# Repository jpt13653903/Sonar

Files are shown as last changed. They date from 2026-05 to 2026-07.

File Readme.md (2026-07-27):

# Sonar

Project used as a teaching aid for the [UCT FPGA course](https://github.com/jpt13653903/UCT-FPGA-Course).

## Overview

This DE10-Lite daughter card features transmitter and receiver array for a 10 kHz sonar system.

Block Diagram

## Flexible Grid

The design features a 64-element grid of microphone sites and a connection matrix that supports 16 output channels.  The user can populate up to 16 microphones and then use the matrix to route them to the receiver channels.

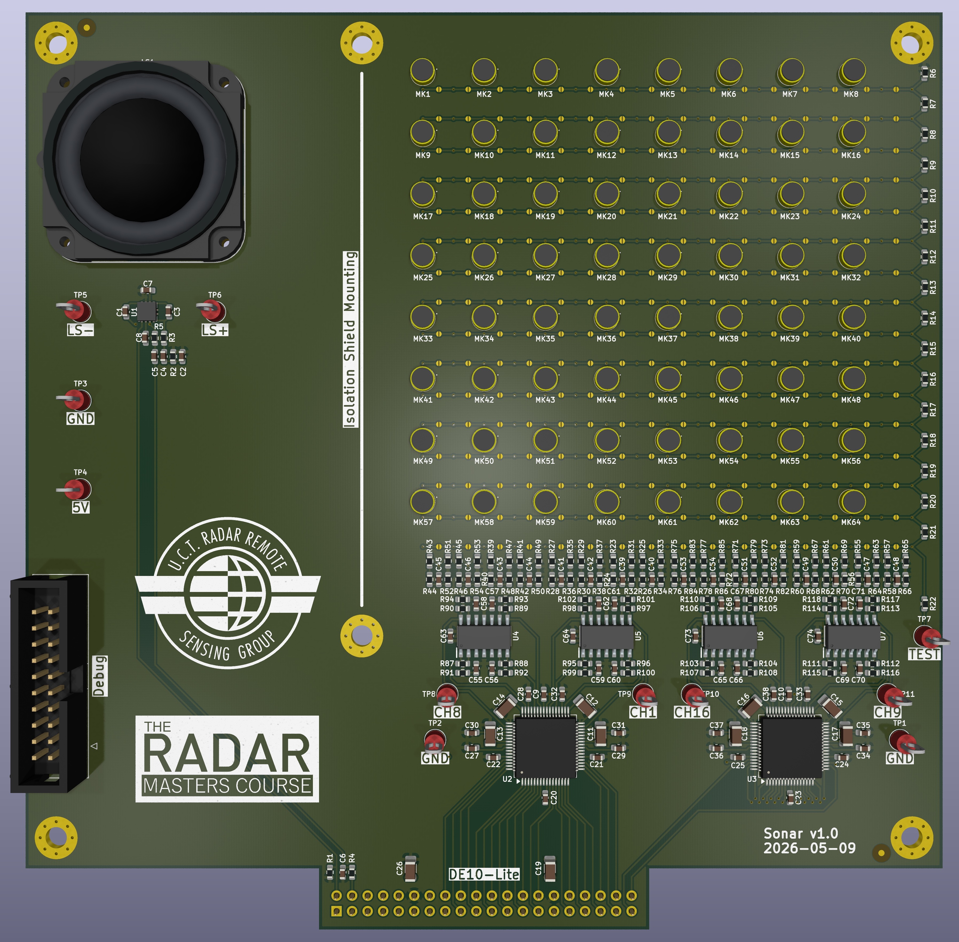
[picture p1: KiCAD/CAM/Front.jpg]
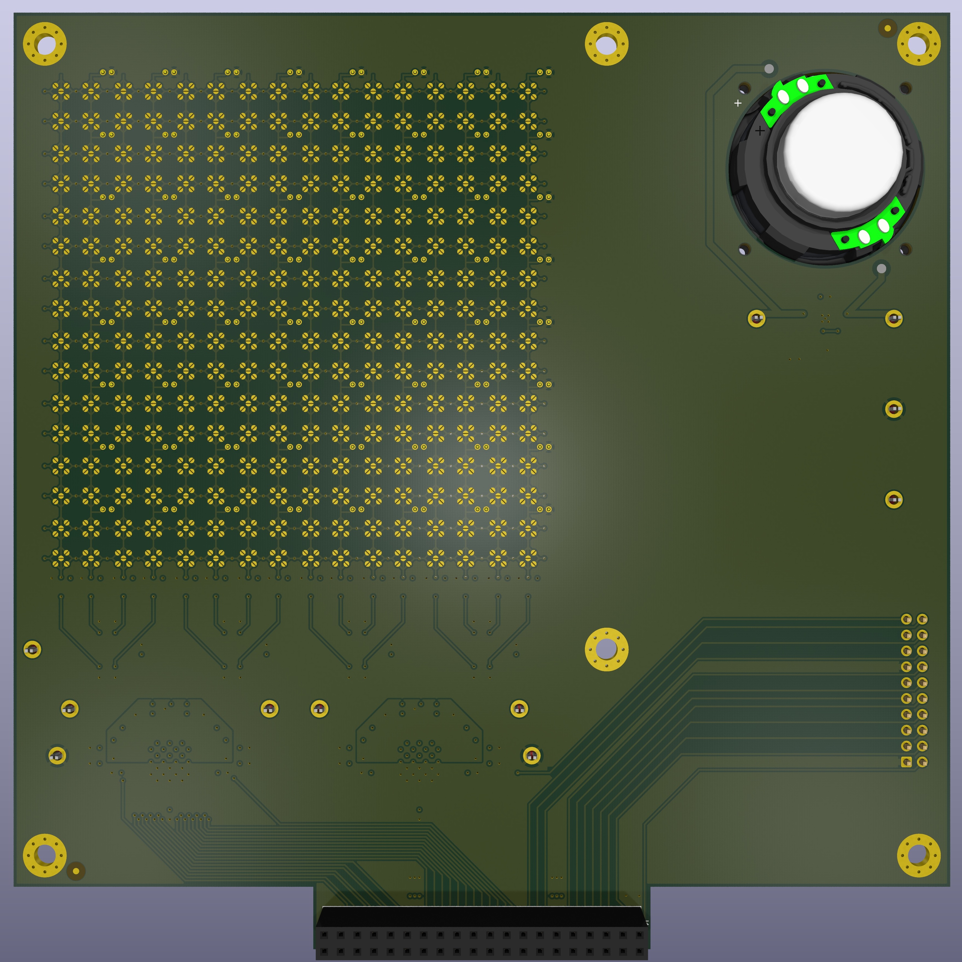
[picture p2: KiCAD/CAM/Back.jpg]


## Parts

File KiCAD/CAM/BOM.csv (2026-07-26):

Reference | Qty | Value | MPN | Manufacturer
C1,C3 | 2 | C0603_100p | KGM15AR71H101K | KYOCERA AVX
C2,C6 | 2 | C0603_2n2 | GRM1885C1H222JA01D | Murata
C4,C5,C8 | 3 | C0603_220n | GCM188R71E224MA55J | Murata
C7,C39,C40,C41,C42,C43,C44,C45,C46,C47,C48,C49,C50,C51,C52,C53,C54 | 17 | C0603_1u0 | GRT188R61H105KE13D | MuRata
C9,C10,C20,C21,C22,C23,C24,C25,C27,C28,C29,C30,C31,C32,C33,C34,C35,C36,C37,C38,C55,C56,C57,C58,C59,C60,C61,C62,C63,C64,C65,C66,C67,C68,C69,C70,C71,C72,C73,C74 | 40 | C0603_100n | 06035C104KAT2A | KYOCERA AVX
C11,C12,C13,C14,C15,C16,C17,C18,C19,C26 | 10 | C1206_22u | C1206C226M4PACTU | Kemet
J1 | 1 | DIN-40-Female | M20-7832042 | Harwin
J2 | 1 | DIN-20 | 70246-2004 | Molex
R1,R2,R4,R91,R92,R93,R94,R99,R100,R101,R102,R107,R108,R109,R110,R115,R116,R117,R118 | 19 | R0603_1k0 | CRGP0603F1K0 | TE Connectivity
R3,R5 | 2 | R0603_12k | CRGP0603F12K | TE Connectivity
R6,R7,R8,R9,R10,R11,R12,R13,R14,R15,R16,R17,R18,R19,R20,R21 | 16 | R0603_10R | CRGP0603F10R | TE Connectivity
R22,R31,R33,R35,R37,R47,R49,R51,R53,R63,R65,R67,R69,R79,R81,R83,R85 | 17 | R0603_3k6 | CRGP0603F3K6 | TE Connectivity
R23,R25,R27,R29,R39,R41,R43,R45,R55,R57,R59,R61,R71,R73,R75,R77 | 16 | R0603_5k6 | CRGP0603F5K6 | TE Connectivity
R24,R26,R28,R30,R32,R34,R36,R38,R40,R42,R44,R46,R48,R50,R52,R54,R56,R58,R60,R62,R64,R66,R68,R70,R72,R74,R76,R78,R80,R82,R84,R86,R87,R88,R89,R90,R95,R96,R97,R98,R103,R104,R105,R106,R111,R112,R113,R114 | 48 | R0603_100k | CRGP0603F100K | TE Connectivity
TP1,TP2,TP3 | 3 | Keystone_5011_Black | 5011 | Keystone
TP4 | 1 | Keystone_5010_Red | 5010 | Keystone
TP5,TP6,TP7,TP8,TP9,TP10,TP11 | 7 | Keystone_5014_Yellow | 5014 | Keystone
U1 | 1 | TPA6211A1DRBR | TPA6211A1DRBR | Texas Instruments
U2,U3 | 2 | MAX11059 | MAX11059ECB+ | Analog Devices
U4,U5,U6,U7 | 4 | AD8534ARZ-REEL | AD8534ARZ-REEL | Analog Devices

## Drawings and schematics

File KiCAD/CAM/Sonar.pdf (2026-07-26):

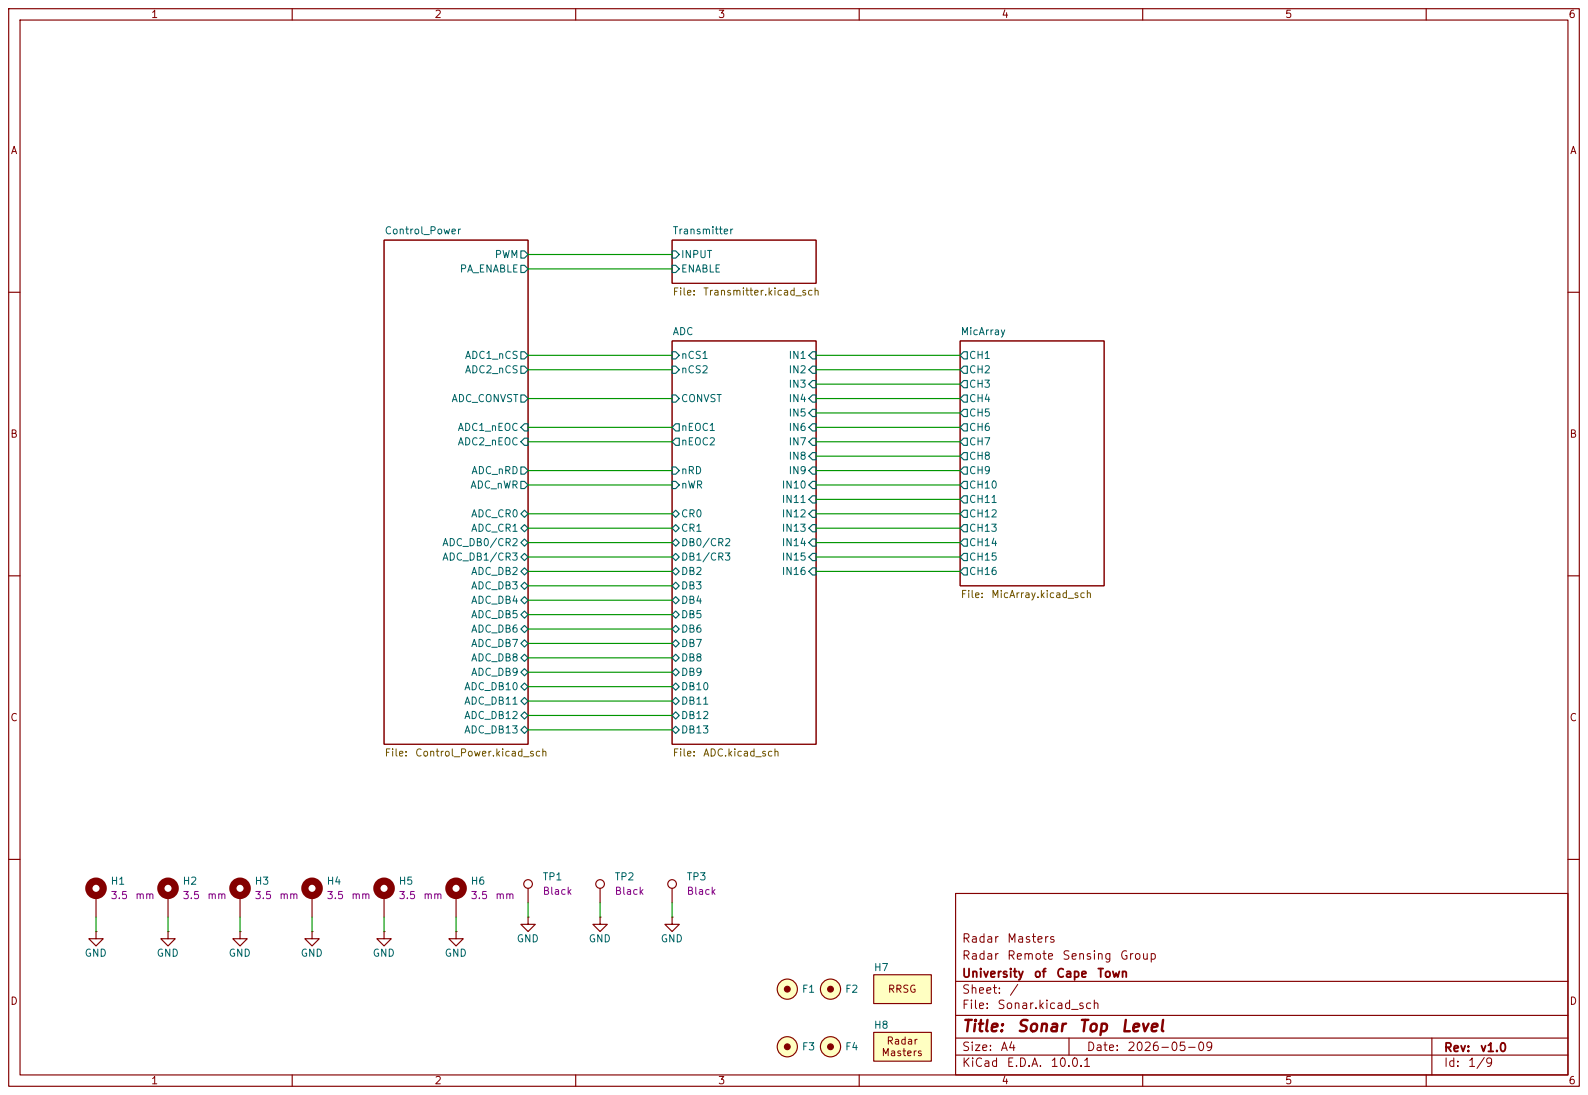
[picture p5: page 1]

Radar Remote Sensing Group
University of Cape Town
Sheet: /
File: Sonar.kicad_sch
Title: Sonar Top Level

Size: A4 | Rev: v1.0
KiCad E.D.A. 10.0.1 | Id: 1/9

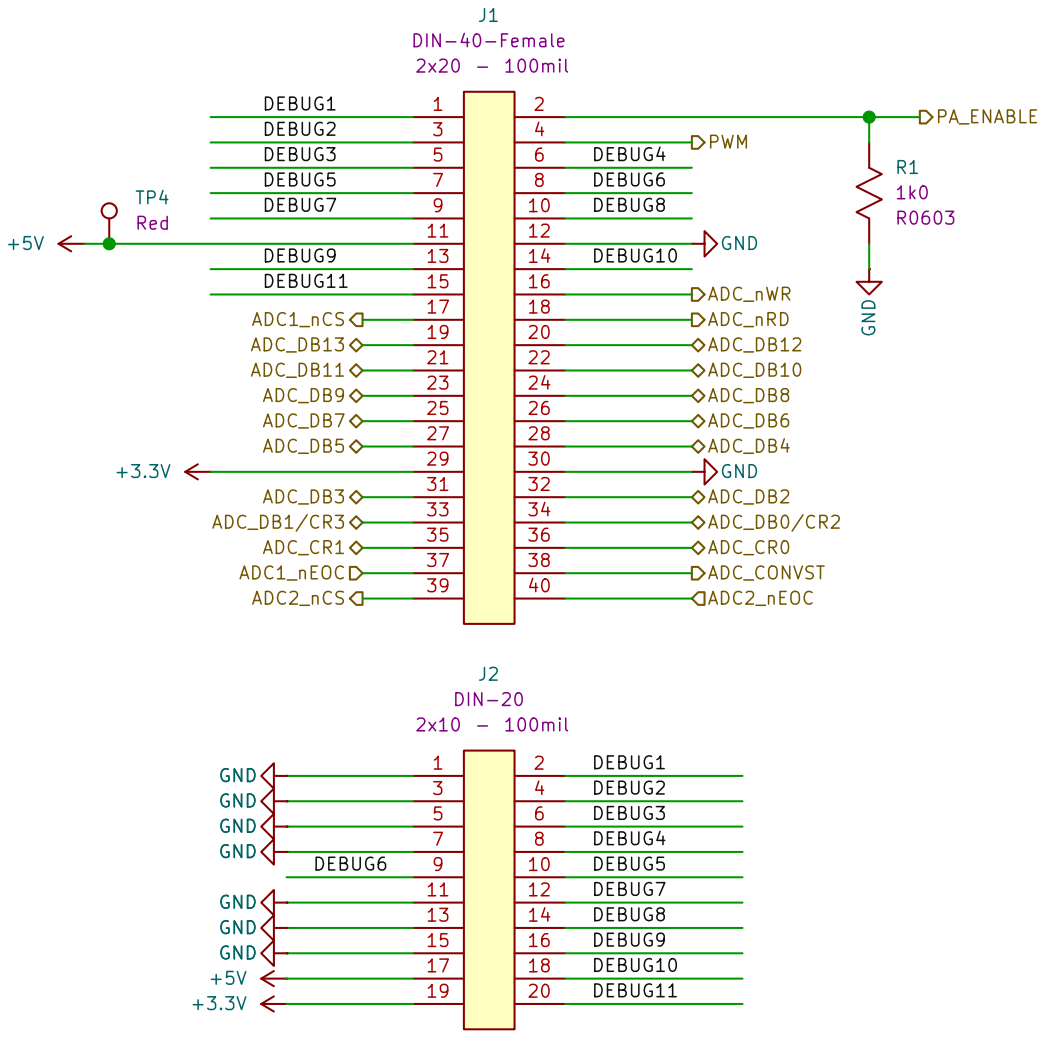
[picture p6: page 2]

Radar Remote Sensing Group
University of Cape Town
Sheet: /Control_Power/
File: Control_Power.kicad_sch
Title: Control and Power

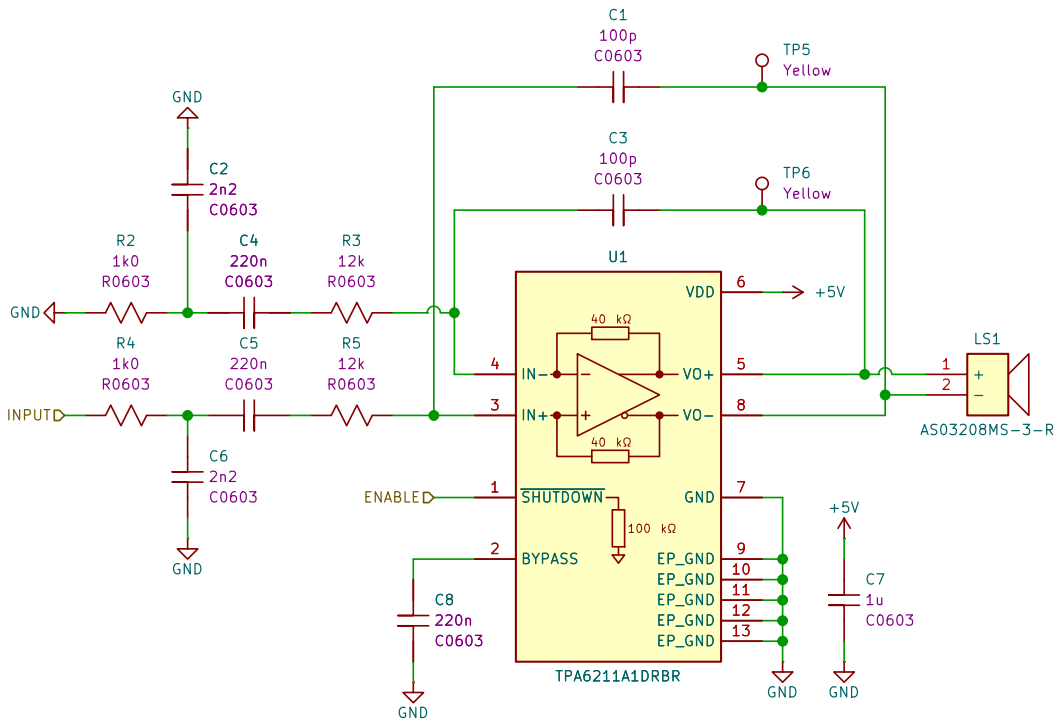
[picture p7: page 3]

Radar Masters
Radar Remote Sensing Group
University of Cape Town
Sheet: /Transmitter/
File: Transmitter.kicad_sch
Title: Transmitter

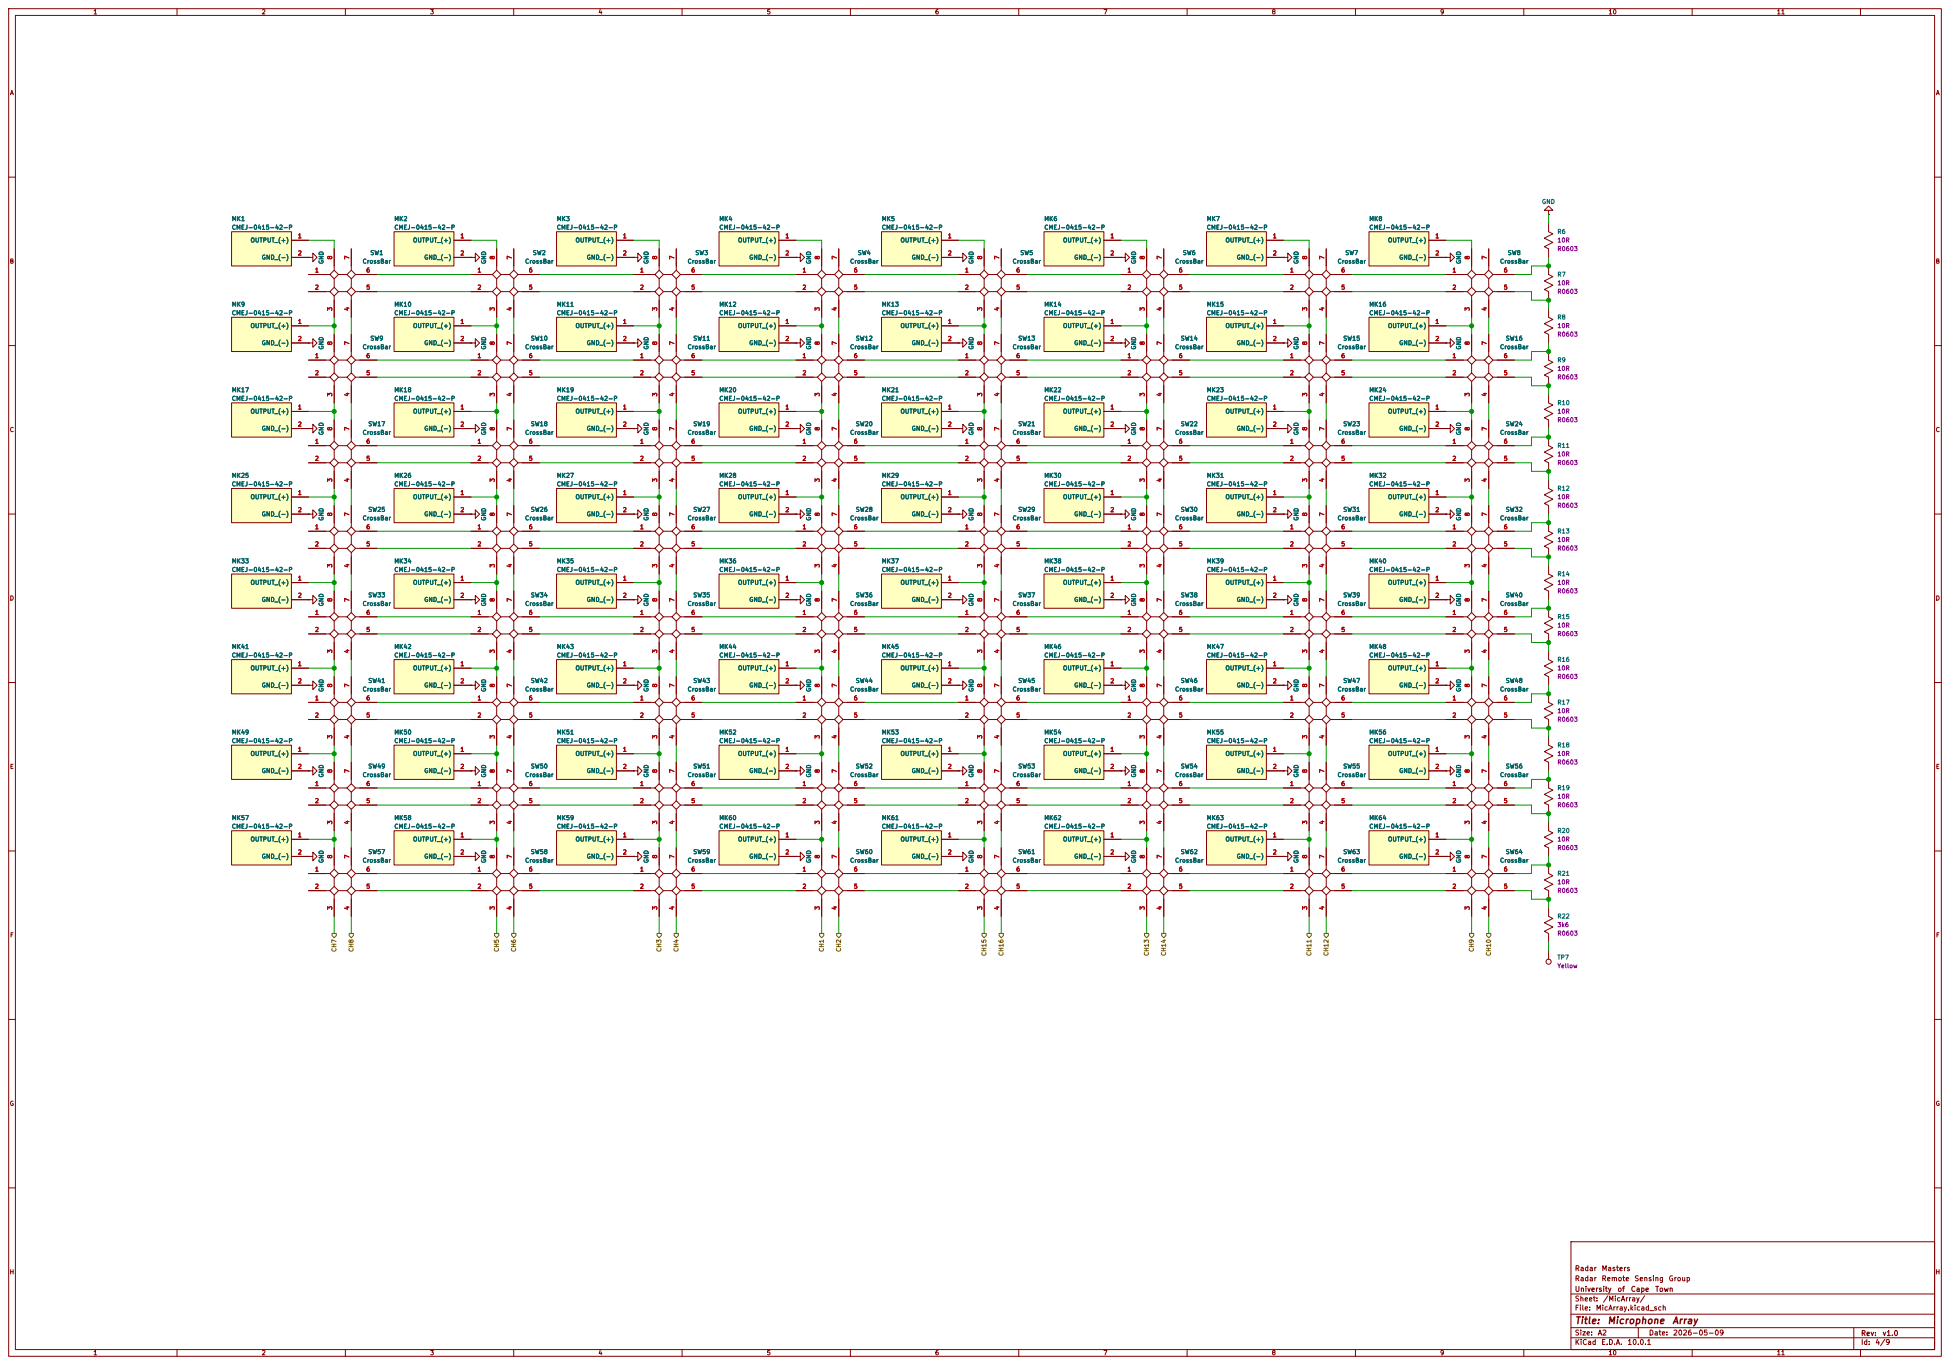
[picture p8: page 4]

7 MK17 CMEJ-0415-42-P OUTPUT_(+) 1 GND_(-) 2 GND MK9 CMEJ-0415-42-P OUTPUT_(+) 1 GND_(-) 2 GND MK1 CMEJ-0415-42-P OUTPUT_(+) 1 GND_(-) 2 GND

7 MK21 CMEJ-0415-42-P OUTPUT_(+) 1 GND_(-) 2 GND GND MK29 CMEJ-0415-42-P OUTPUT_(+) 1 GND_(-) 2 MK13 CMEJ-0415-42-P OUTPUT_(+) 1 GND_(-) 2 MK5 CMEJ-0415-42-P OUTPUT_(+) 1 GND_(-) 2 GND

7GND GND MK24 CMEJ-0415-42-P OUTPUT_(+) 1 GND_(-) 2 MK32 CMEJ-0415-42-P OUTPUT_(+) 1 GND_(-) 2 GND

SW23 CrossBar GND GND GND

7 GND GND MK19 CMEJ-0415-42-P OUTPUT_(+) 1 GND_(-) 2 MK50 CMEJ-0415-42-P OUTPUT_(+) 1 GND_(-) 2

7 MK33 CMEJ-0415-42-P OUTPUT_(+) 1 GND_(-) 2 MK25 CMEJ-0415-42-P OUTPUT_(+) 1 GND_(-) 2 GND GND GND MK59 CMEJ-0415-42-P OUTPUT_(+) 1 GND_(-) 2

7GND MK35 CMEJ-0415-42-P OUTPUT_(+) 1 GND_(-) 2 GND MK43 CMEJ-0415-42-P OUTPUT_(+) 1 GND_(-) 2 GND GND MK27 CMEJ-0415-42-P OUTPUT_(+) 1 GND_(-) 2 MK26 CMEJ-0415-42-P OUTPUT_(+) 1 GND_(-) 2 MK34 CMEJ-0415-42-P OUTPUT_(+) 1 GND_(-) 2

7 MK42 CMEJ-0415-42-P OUTPUT_(+) 1 GND_(-) 2 GND MK41 CMEJ-0415-42-P OUTPUT_(+) 1 GND_(-) 2 GNDSW33 CrossBar 1

7GND MK45 CMEJ-0415-42-P OUTPUT_(+) 1 GND_(-) 2 MK37 CMEJ-0415-42-P OUTPUT_(+) 1 GND_(-) 2 MK38 CMEJ-0415-42-P OUTPUT_(+) 1 GND_(-) 2 MK46 CMEJ-0415-42-P OUTPUT_(+) 1 GND_(-) 2

7GND MK49 CMEJ-0415-42-P OUTPUT_(+) 1 GND_(-) 2 MK57 CMEJ-0415-42-P OUTPUT_(+) 1 GND_(-) 2 GND GND

Radar Masters
Radar Remote Sensing Group
University of Cape Town
Sheet: /MicArray/
File: MicArray.kicad_sch
Title: Microphone Array

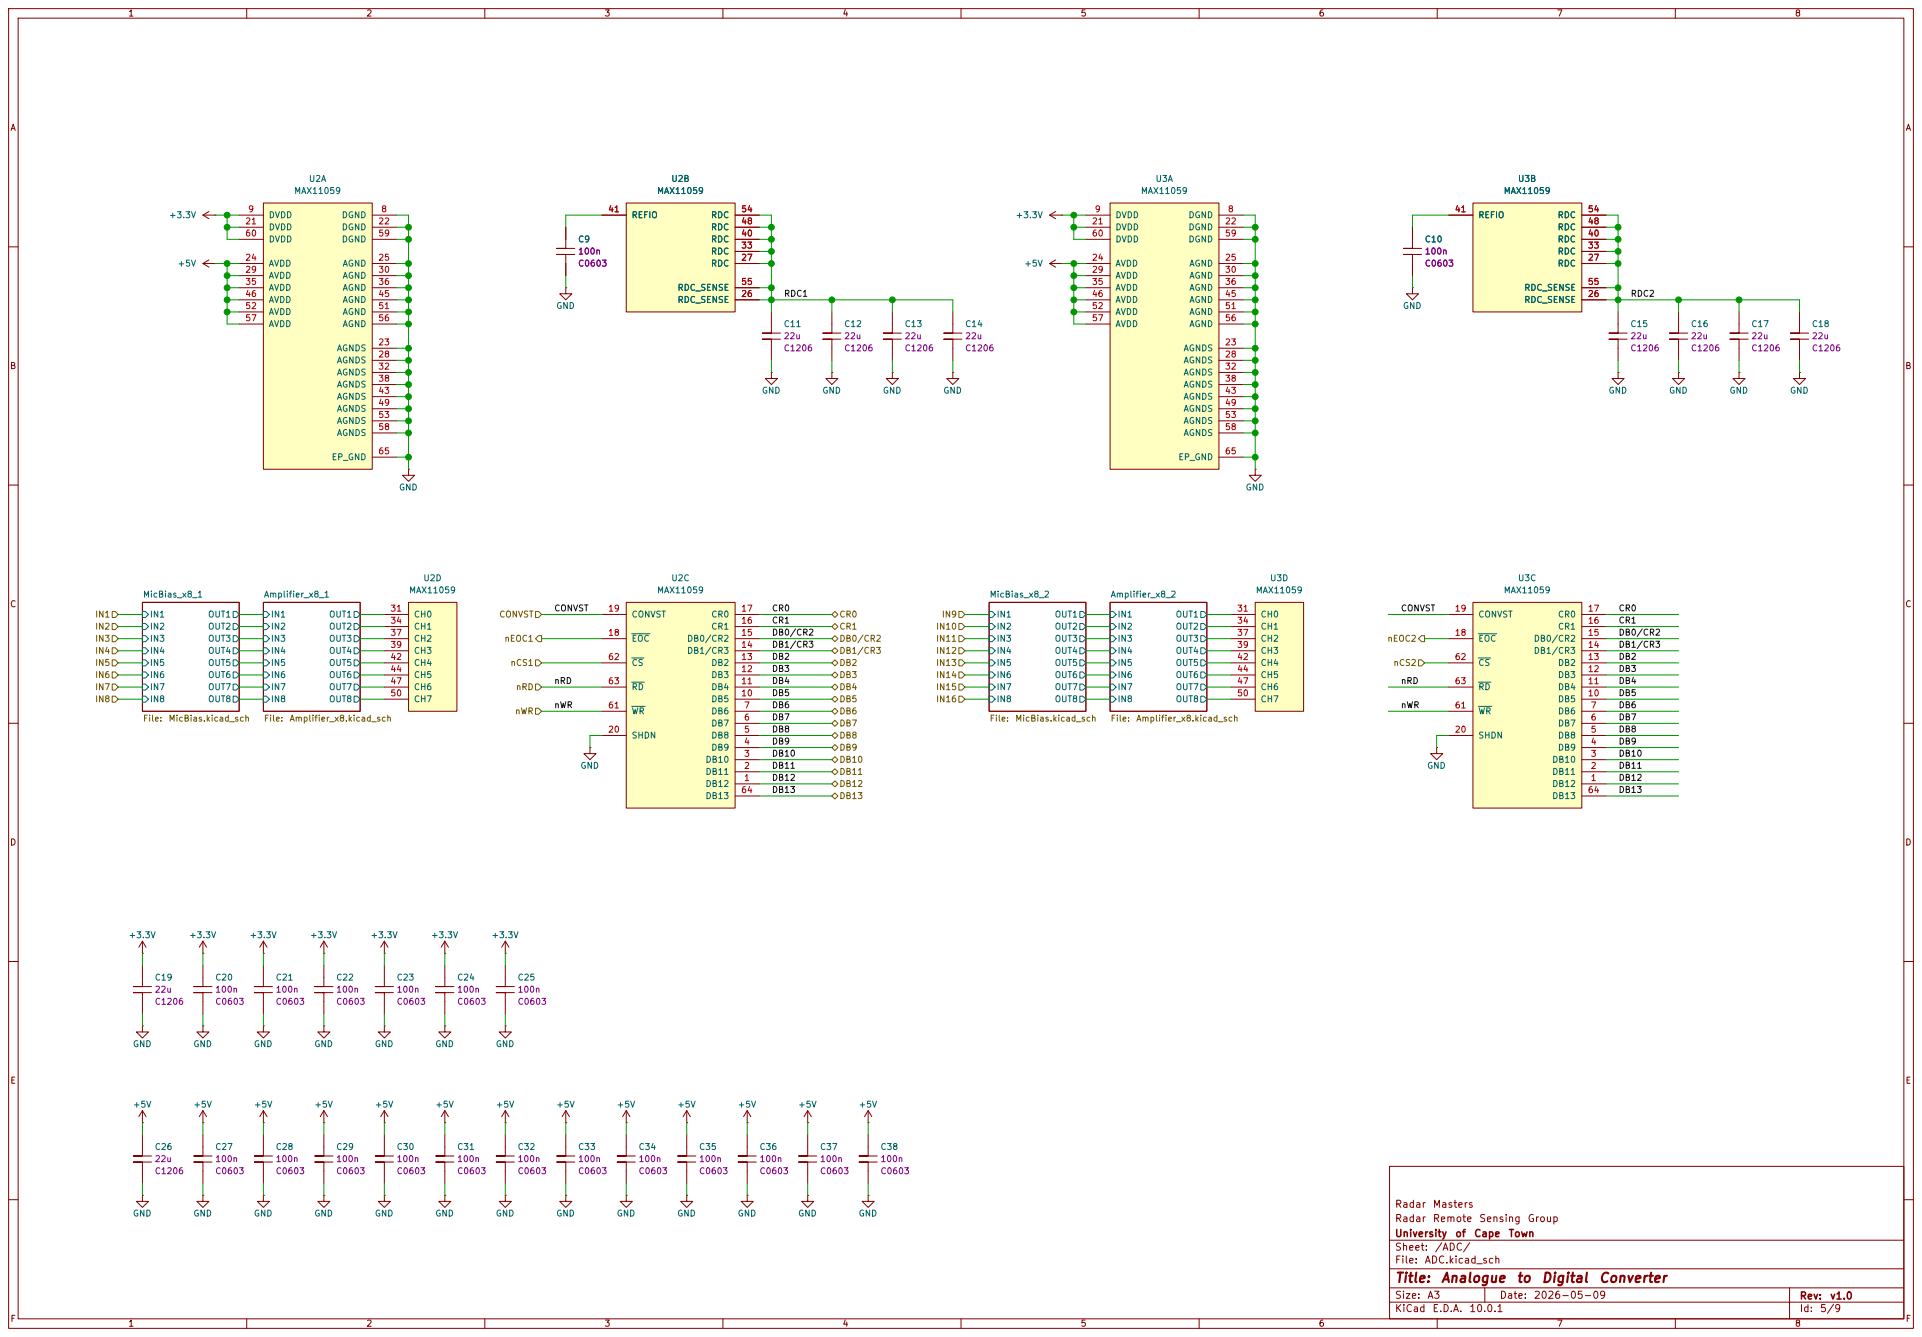
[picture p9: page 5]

Radar Masters
Radar Remote Sensing Group
University of Cape Town
Sheet: /ADC/
File: ADC.kicad_sch
Title: Analogue to Digital Converter

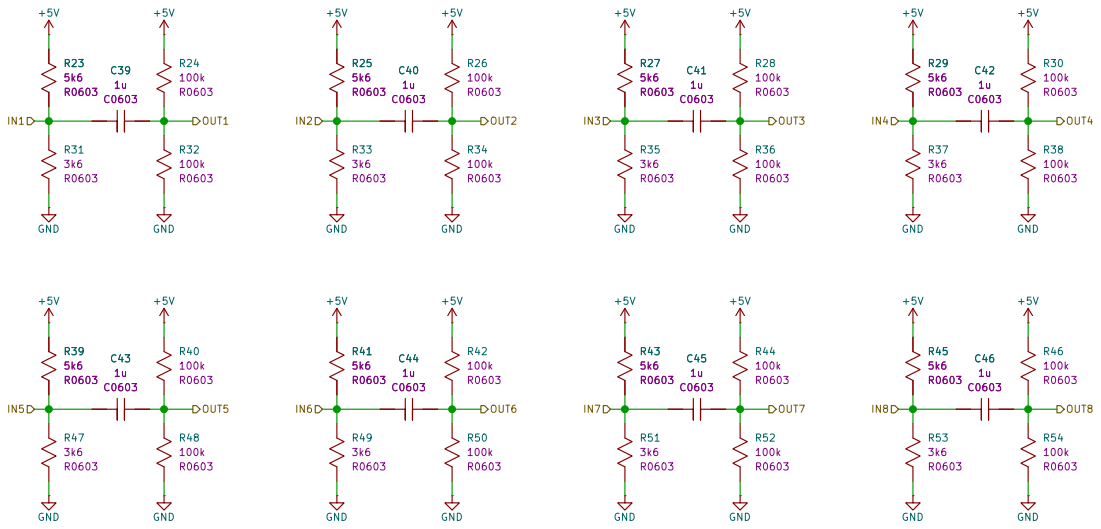
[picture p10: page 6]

Radar Masters
Radar Remote Sensing Group
University of Cape Town
Sheet: /ADC/MicBias_x8_1/
File: MicBias.kicad_sch
Title: Microphone Biassing

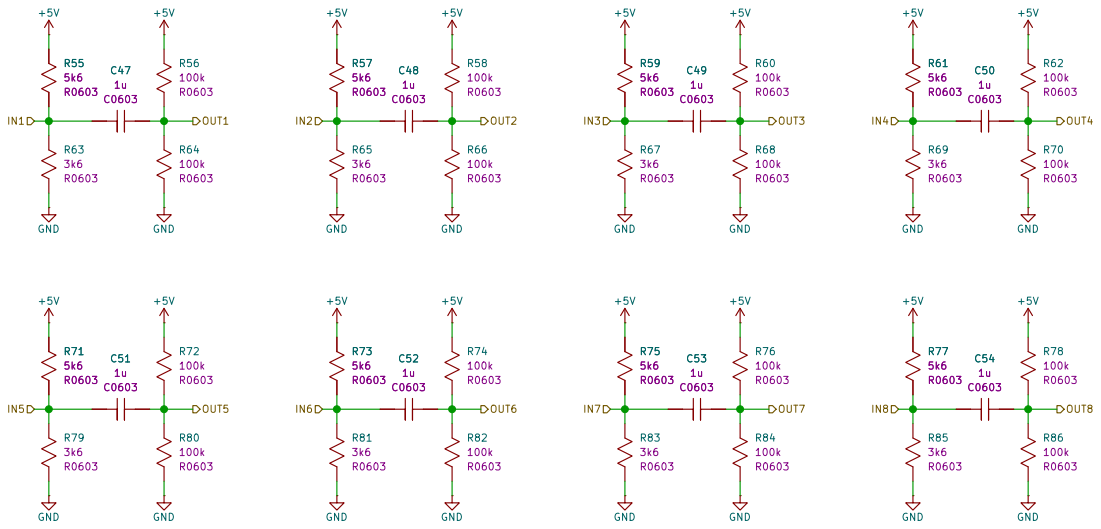
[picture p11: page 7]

Radar Masters
Radar Remote Sensing Group
University of Cape Town
Sheet: /ADC/MicBias_x8_2/
File: MicBias.kicad_sch
Title: Microphone Biassing

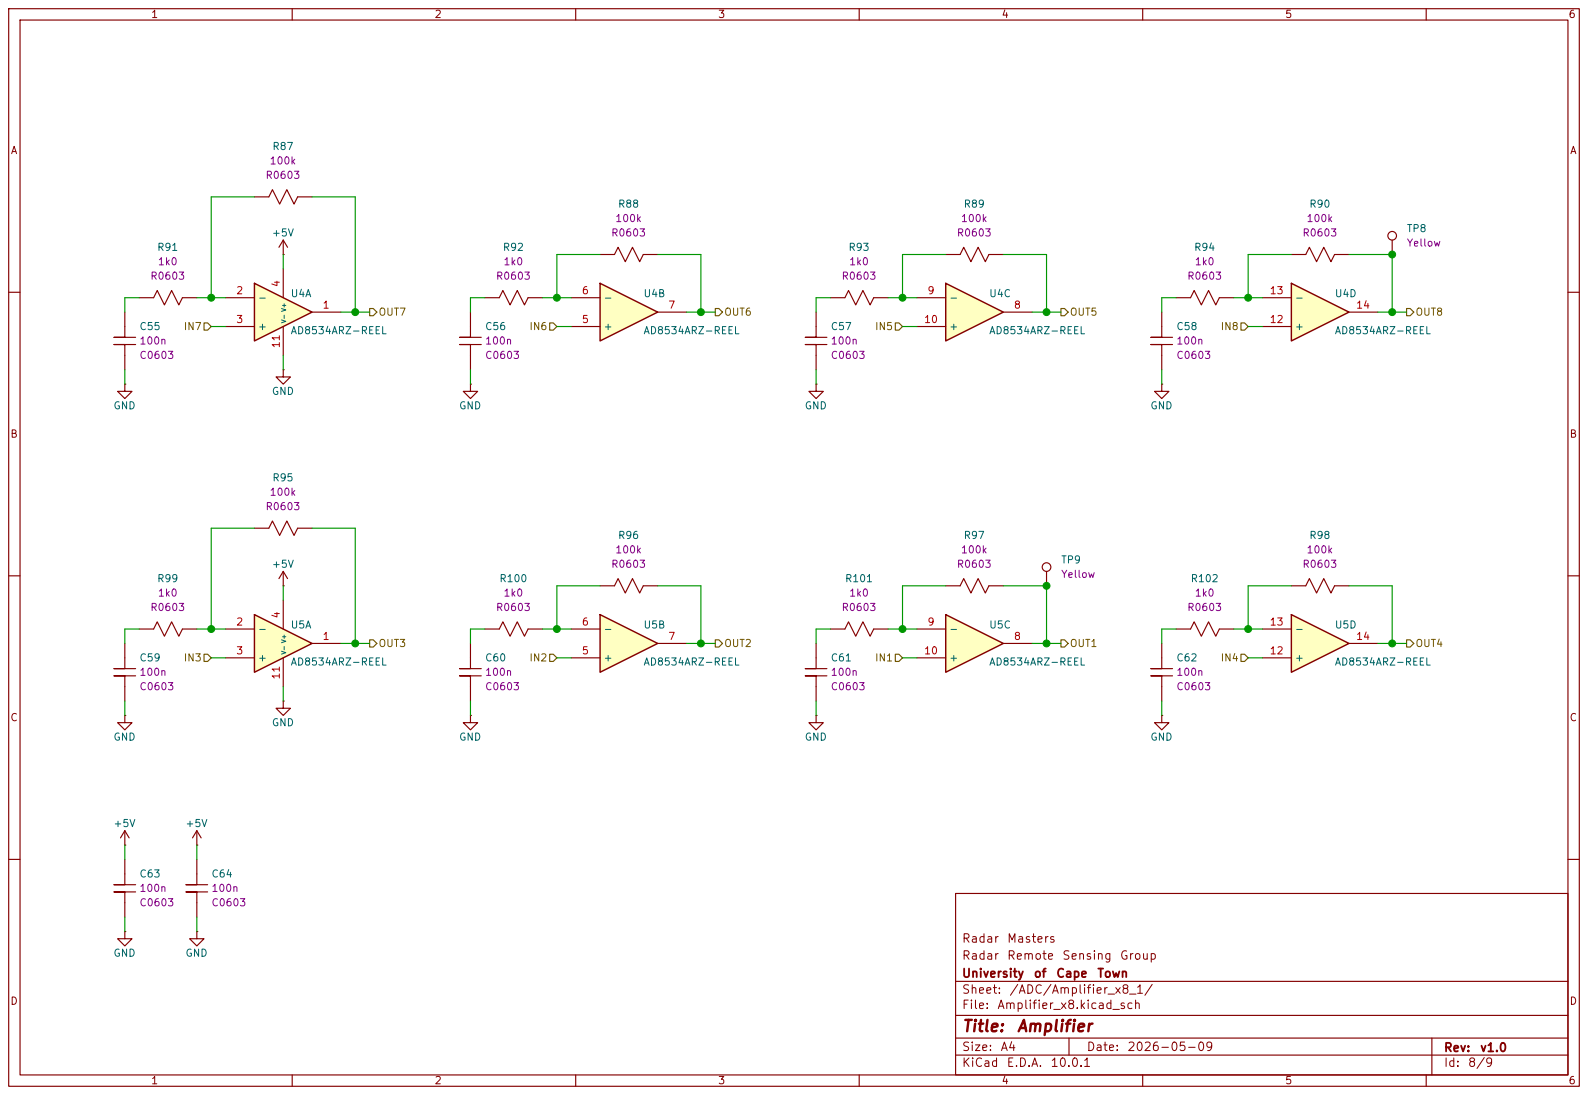
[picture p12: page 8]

Radar Masters
Radar Remote Sensing Group
University of Cape Town
Sheet: /ADC/Amplifier_x8_1/
File: Amplifier_x8.kicad_sch
Title: Amplifier

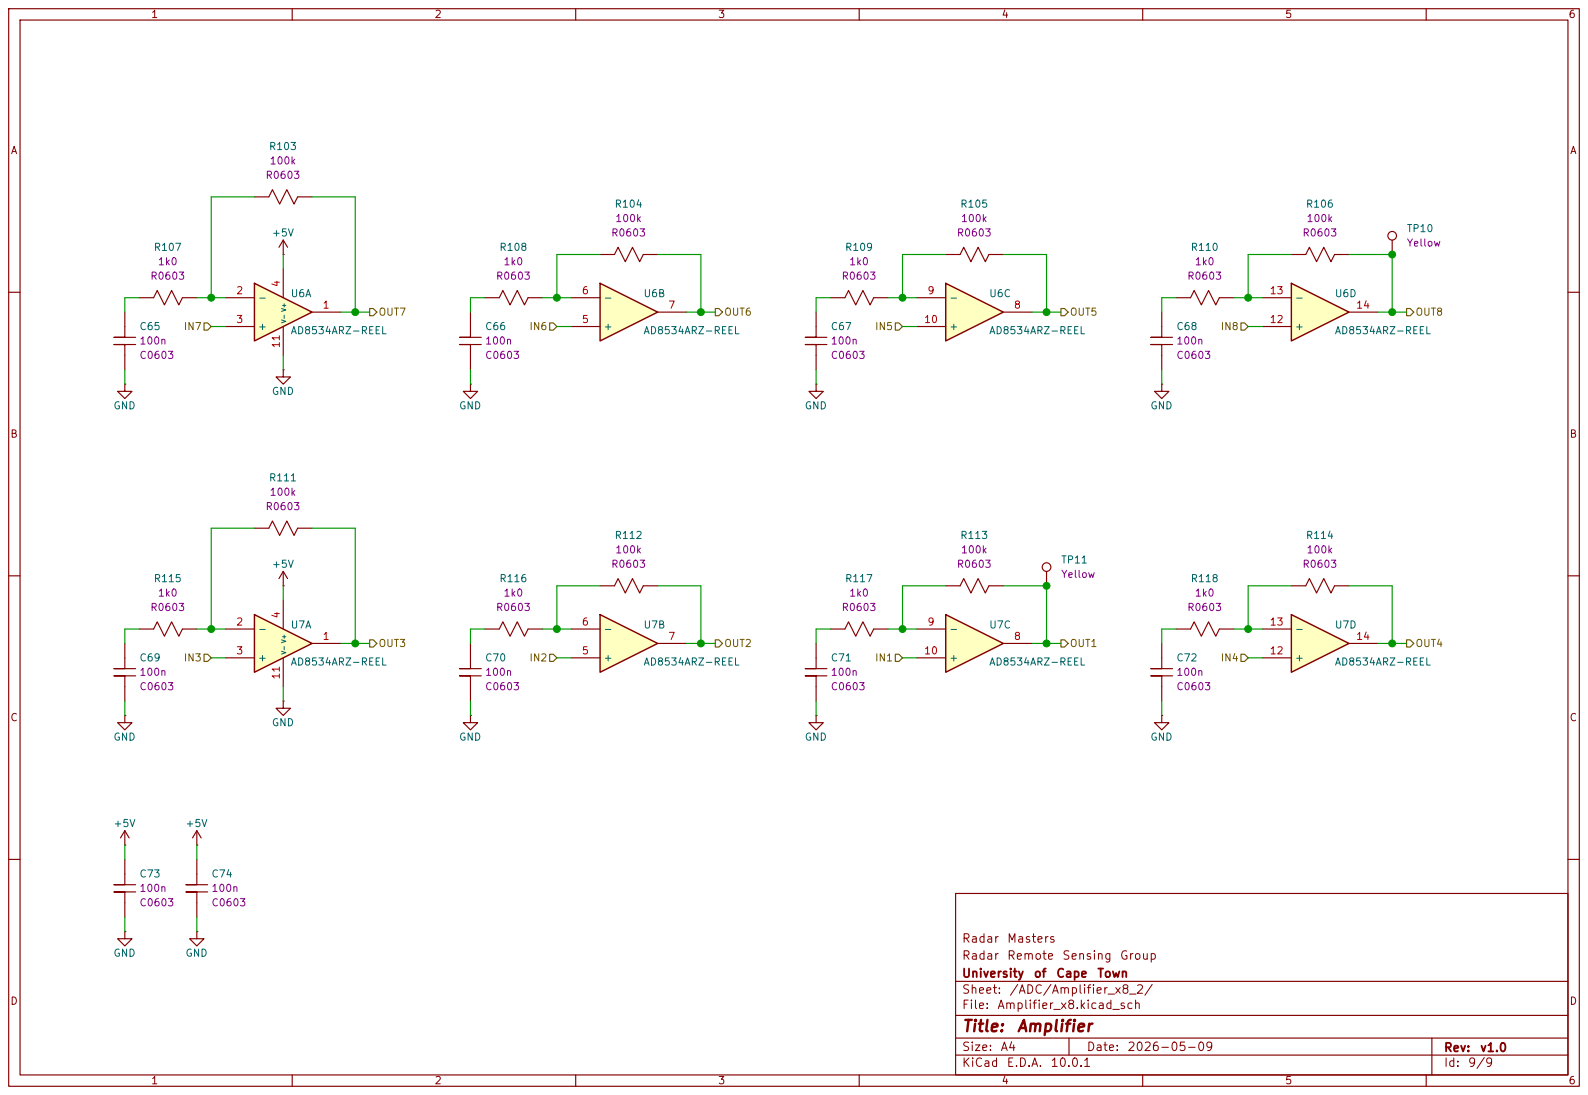
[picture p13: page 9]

Radar Masters
Radar Remote Sensing Group
University of Cape Town
Sheet: /ADC/Amplifier_x8_2/
File: Amplifier_x8.kicad_sch
Title: Amplifier

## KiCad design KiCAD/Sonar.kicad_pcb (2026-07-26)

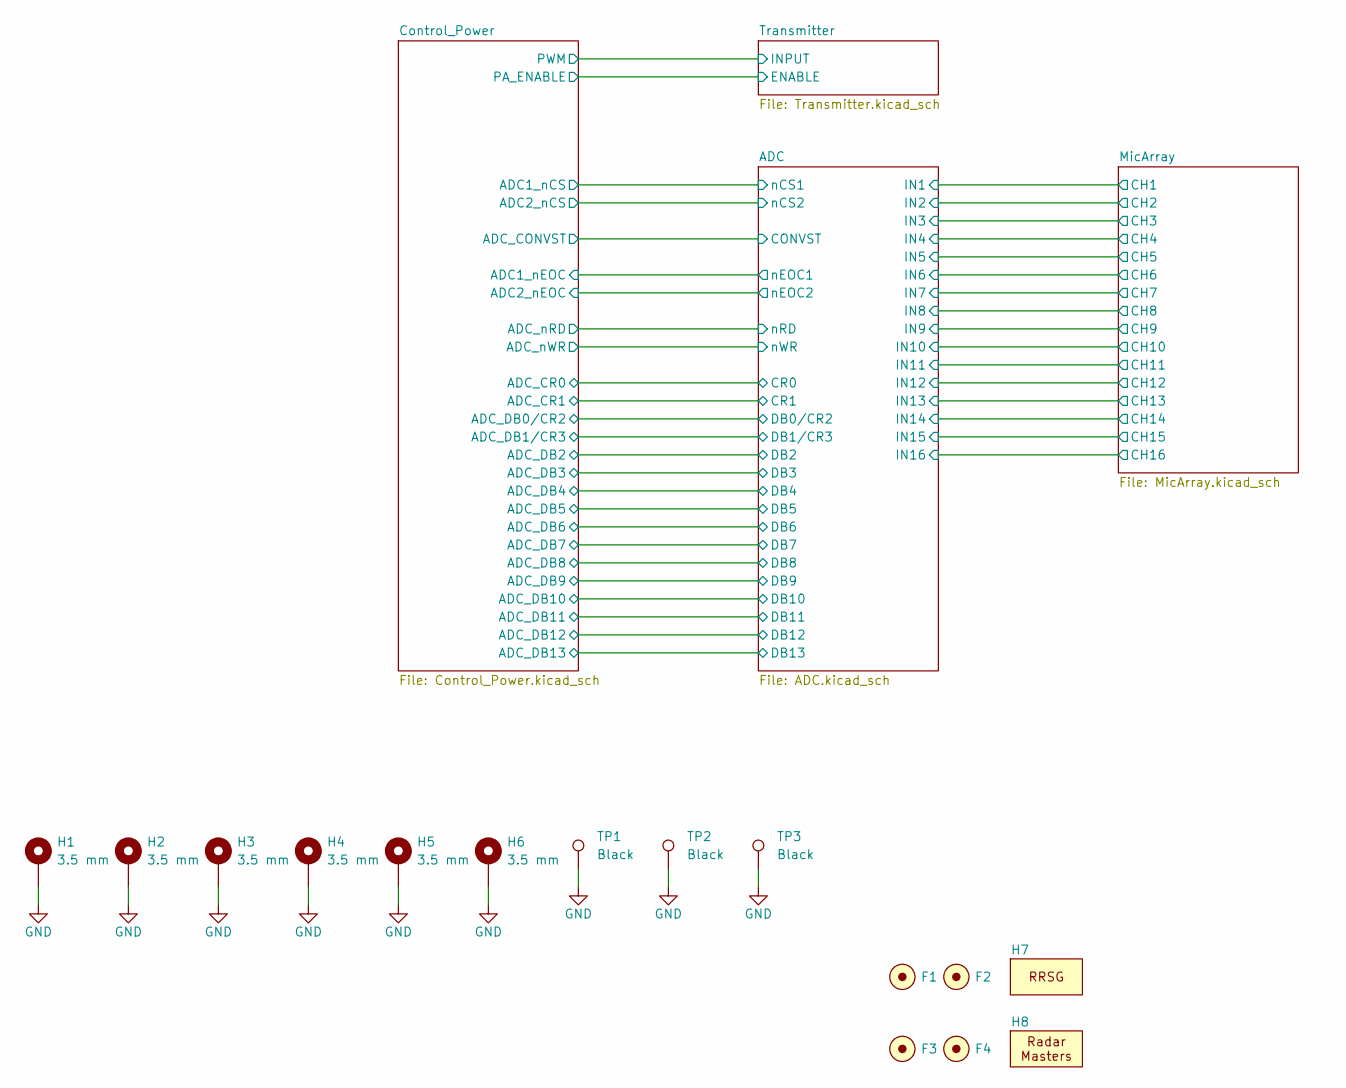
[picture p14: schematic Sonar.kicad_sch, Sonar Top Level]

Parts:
F1, F2, F3, F4: Fiducial_1mm_Mask3mm
H1, H2, H3, H4, H5, H6: MountingHole; MountingHole_3.5mm_Pad_Via
H7: RRSG
H8: RadarMasters
TP1, TP2, TP3: Keystone_5011_Black; TestPoint_Keystone_5010-5014_Multipurpose; MPN 5011

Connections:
GND: H1.1, H2.1, H3.1, H4.1, H5.1, H6.1, TP1.1 (1_1), TP2.1 (1_1), TP3.1 (1_1); also elsewhere on the board

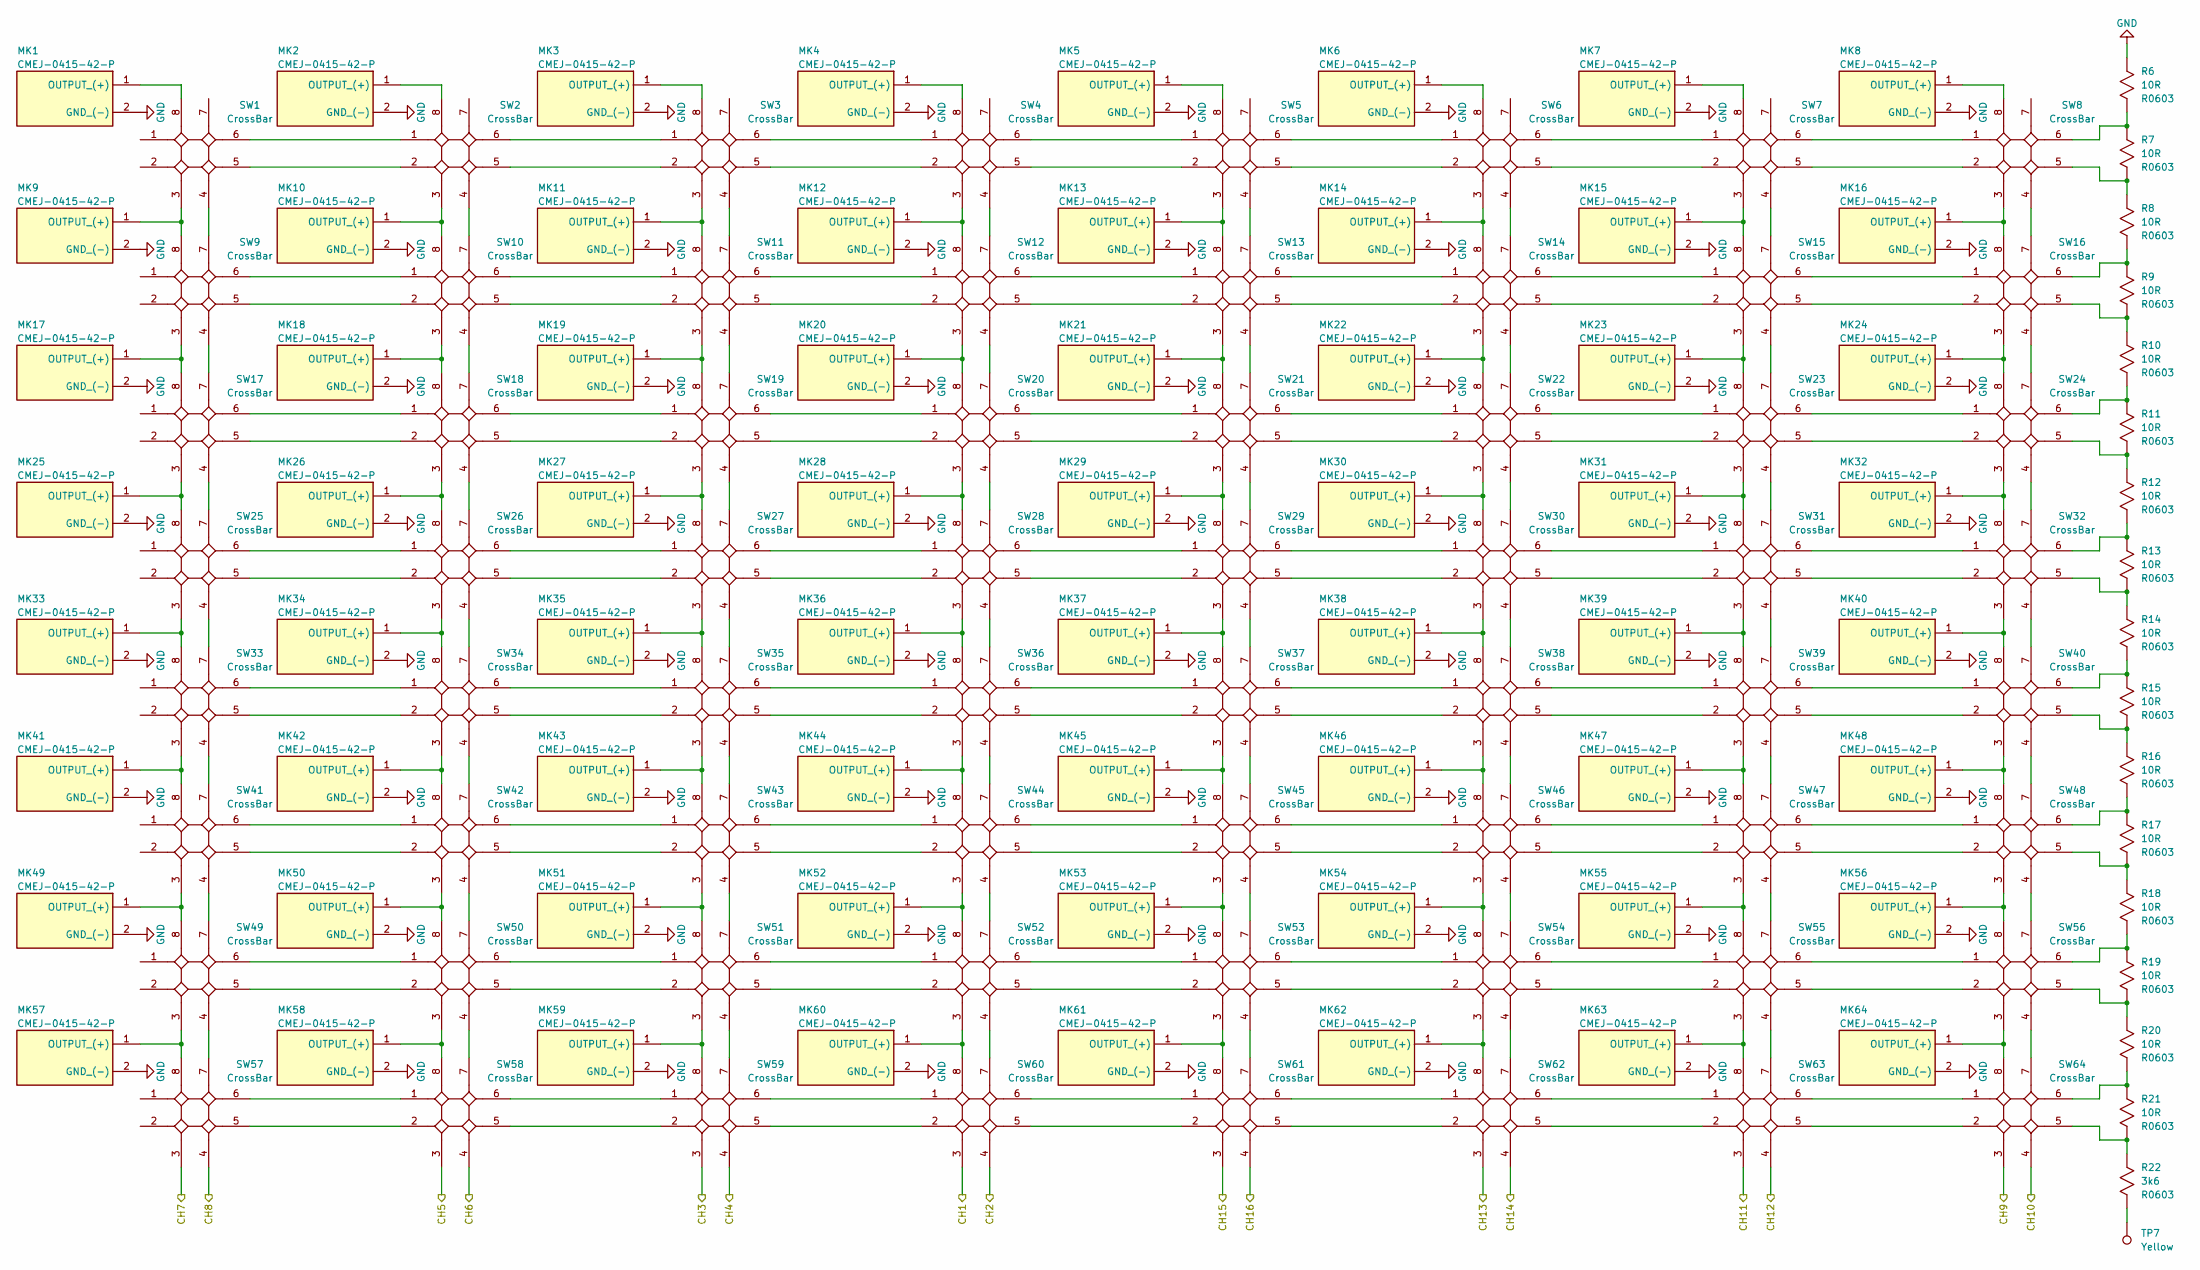
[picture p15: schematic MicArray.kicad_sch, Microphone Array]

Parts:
MK1, MK2, MK3, MK4, MK5, MK6, MK7, MK8, MK9, MK10, MK11, MK12, MK13, MK14, MK15, MK16, MK17, MK18, MK19, MK20, MK21, MK22, MK23, MK24, MK25, MK26, MK27, MK28, MK29, MK30, MK31, MK32, MK33, MK34, MK35, MK36, MK37, MK38, MK39, MK40, MK41, MK42, MK43, MK44, MK45, MK46, MK47, MK48, MK49, MK50, MK51, MK52, MK53, MK54, MK55, MK56, MK57, MK58, MK59, MK60, MK61, MK62, MK63, MK64: CMEJ-0415-42-P; CMEJ041542P; MPN CMEJ-0415-42-P
R6, R7, R8, R9, R10, R11, R12, R13, R14, R15, R16, R17, R18, R19, R20, R21: R0603_10R; R_0603_1608Metric; MPN CRGP0603F10R
R22: R0603_3k6; R_0603_1608Metric; MPN CRGP0603F3K6
SW1, SW2, SW3, SW4, SW5, SW6, SW7, SW8, SW9, SW10, SW11, SW12, SW13, SW14, SW15, SW16, SW17, SW18, SW19, SW20, SW21, SW22, SW23, SW24, SW25, SW26, SW27, SW28, SW29, SW30, SW31, SW32, SW33, SW34, SW35, SW36, SW37, SW38, SW39, SW40, SW41, SW42, SW43, SW44, SW45, SW46, SW47, SW48, SW49, SW50, SW51, SW52, SW53, SW54, SW55, SW56, SW57, SW58, SW59, SW60, SW61, SW62, SW63, SW64: CrossBar; CrossBar_2x2
TP7: Keystone_5014_Yellow; TestPoint_Keystone_5010-5014_Multipurpose; MPN 5014

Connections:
/ADC/IN1: SW60.3 (OUTPUT_(+)); also elsewhere on the board
/ADC/IN2: SW60.4 (GND_(-)); also elsewhere on the board
/ADC/IN3: SW59.3 (OUTPUT_(+)); also elsewhere on the board
/ADC/IN4: SW59.4 (GND_(-)); also elsewhere on the board
/ADC/IN5: SW58.3 (OUTPUT_(+)); also elsewhere on the board
/ADC/IN6: SW58.4 (GND_(-)); also elsewhere on the board
/ADC/IN7: SW57.3 (OUTPUT_(+)); also elsewhere on the board
/ADC/IN8: SW57.4 (GND_(-)); also elsewhere on the board
/ADC/IN9: SW64.3 (OUTPUT_(+)); also elsewhere on the board
/ADC/IN10: SW64.4 (GND_(-)); also elsewhere on the board
/ADC/IN11: SW63.3 (OUTPUT_(+)); also elsewhere on the board
/ADC/IN12: SW63.4 (GND_(-)); also elsewhere on the board
/ADC/IN13: SW62.3 (OUTPUT_(+)); also elsewhere on the board
/ADC/IN14: SW62.4 (GND_(-)); also elsewhere on the board
/ADC/IN15: SW61.3 (OUTPUT_(+)); also elsewhere on the board
/ADC/IN16: SW61.4 (GND_(-)); also elsewhere on the board
GND: MK1.2 (GND_(-)), MK2.2 (GND_(-)), MK3.2 (GND_(-)), MK4.2 (GND_(-)), MK5.2 (GND_(-)), MK6.2 (GND_(-)), MK7.2 (GND_(-)), MK8.2 (GND_(-)), MK9.2 (GND_(-)), MK10.2 (GND_(-)), MK11.2 (GND_(-)), MK12.2 (GND_(-)), MK13.2 (GND_(-)), MK14.2 (GND_(-)), MK15.2 (GND_(-)), MK16.2 (GND_(-)), MK17.2 (GND_(-)), MK18.2 (GND_(-)), MK19.2 (GND_(-)), MK20.2 (GND_(-)), MK21.2 (GND_(-)), MK22.2 (GND_(-)), MK23.2 (GND_(-)), MK24.2 (GND_(-)), MK25.2 (GND_(-)), MK26.2 (GND_(-)), MK27.2 (GND_(-)), MK28.2 (GND_(-)), MK29.2 (GND_(-)), MK30.2 (GND_(-)), MK31.2 (GND_(-)), MK32.2 (GND_(-)), MK33.2 (GND_(-)), MK34.2 (GND_(-)), MK35.2 (GND_(-)), MK36.2 (GND_(-)), MK37.2 (GND_(-)), MK38.2 (GND_(-)), MK39.2 (GND_(-)), MK40.2 (GND_(-)), MK41.2 (GND_(-)), MK42.2 (GND_(-)), MK43.2 (GND_(-)), MK44.2 (GND_(-)), MK45.2 (GND_(-)), MK46.2 (GND_(-)), MK47.2 (GND_(-)), MK48.2 (GND_(-)), MK49.2 (GND_(-)), MK50.2 (GND_(-)), MK51.2 (GND_(-)), MK52.2 (GND_(-)), MK53.2 (GND_(-)), MK54.2 (GND_(-)), MK55.2 (GND_(-)), MK56.2 (GND_(-)), MK57.2 (GND_(-)), MK58.2 (GND_(-)), MK59.2 (GND_(-)), MK60.2 (GND_(-)), MK61.2 (GND_(-)), MK62.2 (GND_(-)), MK63.2 (GND_(-)), MK64.2 (GND_(-)), R6.1; also elsewhere on the board
unnamed: MK1.1 (OUTPUT_(+)), SW1.8 (OUTPUT_(+))
unnamed: MK2.1 (OUTPUT_(+)), SW2.8 (OUTPUT_(+))
unnamed: MK3.1 (OUTPUT_(+)), SW3.8 (OUTPUT_(+))
unnamed: MK4.1 (OUTPUT_(+)), SW4.8 (OUTPUT_(+))
unnamed: MK5.1 (OUTPUT_(+)), SW5.8 (OUTPUT_(+))
unnamed: MK6.1 (OUTPUT_(+)), SW6.8 (OUTPUT_(+))
unnamed: MK7.1 (OUTPUT_(+)), SW7.8 (OUTPUT_(+))
unnamed: MK8.1 (OUTPUT_(+)), SW8.8 (OUTPUT_(+))
unnamed: MK9.1 (OUTPUT_(+)), SW1.3 (OUTPUT_(+)), SW9.8 (OUTPUT_(+))
unnamed: MK10.1 (OUTPUT_(+)), SW2.3 (OUTPUT_(+)), SW10.8 (OUTPUT_(+))
unnamed: MK11.1 (OUTPUT_(+)), SW3.3 (OUTPUT_(+)), SW11.8 (OUTPUT_(+))
unnamed: MK12.1 (OUTPUT_(+)), SW4.3 (OUTPUT_(+)), SW12.8 (OUTPUT_(+))
unnamed: MK13.1 (OUTPUT_(+)), SW5.3 (OUTPUT_(+)), SW13.8 (OUTPUT_(+))
unnamed: MK14.1 (OUTPUT_(+)), SW6.3 (OUTPUT_(+)), SW14.8 (OUTPUT_(+))
unnamed: MK15.1 (OUTPUT_(+)), SW7.3 (OUTPUT_(+)), SW15.8 (OUTPUT_(+))
unnamed: MK16.1 (OUTPUT_(+)), SW8.3 (OUTPUT_(+)), SW16.8 (OUTPUT_(+))
unnamed: MK17.1 (OUTPUT_(+)), SW9.3 (OUTPUT_(+)), SW17.8 (OUTPUT_(+))
unnamed: MK18.1 (OUTPUT_(+)), SW10.3 (OUTPUT_(+)), SW18.8 (OUTPUT_(+))
unnamed: MK19.1 (OUTPUT_(+)), SW11.3 (OUTPUT_(+)), SW19.8 (OUTPUT_(+))
unnamed: MK20.1 (OUTPUT_(+)), SW12.3 (OUTPUT_(+)), SW20.8 (OUTPUT_(+))
unnamed: MK21.1 (OUTPUT_(+)), SW13.3 (OUTPUT_(+)), SW21.8 (OUTPUT_(+))
unnamed: MK22.1 (OUTPUT_(+)), SW14.3 (OUTPUT_(+)), SW22.8 (OUTPUT_(+))
unnamed: MK23.1 (OUTPUT_(+)), SW15.3 (OUTPUT_(+)), SW23.8 (OUTPUT_(+))
unnamed: MK24.1 (OUTPUT_(+)), SW16.3 (OUTPUT_(+)), SW24.8 (OUTPUT_(+))
unnamed: MK25.1 (OUTPUT_(+)), SW17.3 (OUTPUT_(+)), SW25.8 (OUTPUT_(+))
unnamed: MK26.1 (OUTPUT_(+)), SW18.3 (OUTPUT_(+)), SW26.8 (OUTPUT_(+))
unnamed: MK27.1 (OUTPUT_(+)), SW19.3 (OUTPUT_(+)), SW27.8 (OUTPUT_(+))
unnamed: MK28.1 (OUTPUT_(+)), SW20.3 (OUTPUT_(+)), SW28.8 (OUTPUT_(+))
unnamed: MK29.1 (OUTPUT_(+)), SW21.3 (OUTPUT_(+)), SW29.8 (OUTPUT_(+))
unnamed: MK30.1 (OUTPUT_(+)), SW22.3 (OUTPUT_(+)), SW30.8 (OUTPUT_(+))
unnamed: MK31.1 (OUTPUT_(+)), SW23.3 (OUTPUT_(+)), SW31.8 (OUTPUT_(+))
unnamed: MK32.1 (OUTPUT_(+)), SW24.3 (OUTPUT_(+)), SW32.8 (OUTPUT_(+))
unnamed: MK33.1 (OUTPUT_(+)), SW25.3 (OUTPUT_(+)), SW33.8 (OUTPUT_(+))
unnamed: MK34.1 (OUTPUT_(+)), SW26.3 (OUTPUT_(+)), SW34.8 (OUTPUT_(+))
unnamed: MK35.1 (OUTPUT_(+)), SW27.3 (OUTPUT_(+)), SW35.8 (OUTPUT_(+))
unnamed: MK36.1 (OUTPUT_(+)), SW28.3 (OUTPUT_(+)), SW36.8 (OUTPUT_(+))
unnamed: MK37.1 (OUTPUT_(+)), SW29.3 (OUTPUT_(+)), SW37.8 (OUTPUT_(+))
unnamed: MK38.1 (OUTPUT_(+)), SW30.3 (OUTPUT_(+)), SW38.8 (OUTPUT_(+))
unnamed: MK39.1 (OUTPUT_(+)), SW31.3 (OUTPUT_(+)), SW39.8 (OUTPUT_(+))
unnamed: MK40.1 (OUTPUT_(+)), SW32.3 (OUTPUT_(+)), SW40.8 (OUTPUT_(+))
unnamed: MK41.1 (OUTPUT_(+)), SW33.3 (OUTPUT_(+)), SW41.8 (OUTPUT_(+))
unnamed: MK42.1 (OUTPUT_(+)), SW34.3 (OUTPUT_(+)), SW42.8 (OUTPUT_(+))
unnamed: MK43.1 (OUTPUT_(+)), SW35.3 (OUTPUT_(+)), SW43.8 (OUTPUT_(+))
unnamed: MK44.1 (OUTPUT_(+)), SW36.3 (OUTPUT_(+)), SW44.8 (OUTPUT_(+))
unnamed: MK45.1 (OUTPUT_(+)), SW37.3 (OUTPUT_(+)), SW45.8 (OUTPUT_(+))
unnamed: MK46.1 (OUTPUT_(+)), SW38.3 (OUTPUT_(+)), SW46.8 (OUTPUT_(+))
unnamed: MK47.1 (OUTPUT_(+)), SW39.3 (OUTPUT_(+)), SW47.8 (OUTPUT_(+))
unnamed: MK48.1 (OUTPUT_(+)), SW40.3 (OUTPUT_(+)), SW48.8 (OUTPUT_(+))
unnamed: MK49.1 (OUTPUT_(+)), SW41.3 (OUTPUT_(+)), SW49.8 (OUTPUT_(+))
unnamed: MK50.1 (OUTPUT_(+)), SW42.3 (OUTPUT_(+)), SW50.8 (OUTPUT_(+))
unnamed: MK51.1 (OUTPUT_(+)), SW43.3 (OUTPUT_(+)), SW51.8 (OUTPUT_(+))
unnamed: MK52.1 (OUTPUT_(+)), SW44.3 (OUTPUT_(+)), SW52.8 (OUTPUT_(+))
unnamed: MK53.1 (OUTPUT_(+)), SW45.3 (OUTPUT_(+)), SW53.8 (OUTPUT_(+))
unnamed: MK54.1 (OUTPUT_(+)), SW46.3 (OUTPUT_(+)), SW54.8 (OUTPUT_(+))
unnamed: MK55.1 (OUTPUT_(+)), SW47.3 (OUTPUT_(+)), SW55.8 (OUTPUT_(+))
unnamed: MK56.1 (OUTPUT_(+)), SW48.3 (OUTPUT_(+)), SW56.8 (OUTPUT_(+))
unnamed: MK57.1 (OUTPUT_(+)), SW49.3 (OUTPUT_(+)), SW57.8 (OUTPUT_(+))
unnamed: MK58.1 (OUTPUT_(+)), SW50.3 (OUTPUT_(+)), SW58.8 (OUTPUT_(+))
unnamed: MK59.1 (OUTPUT_(+)), SW51.3 (OUTPUT_(+)), SW59.8 (OUTPUT_(+))
unnamed: MK60.1 (OUTPUT_(+)), SW52.3 (OUTPUT_(+)), SW60.8 (OUTPUT_(+))
unnamed: MK61.1 (OUTPUT_(+)), SW53.3 (OUTPUT_(+)), SW61.8 (OUTPUT_(+))
unnamed: MK62.1 (OUTPUT_(+)), SW54.3 (OUTPUT_(+)), SW62.8 (OUTPUT_(+))
unnamed: MK63.1 (OUTPUT_(+)), SW55.3 (OUTPUT_(+)), SW63.8 (OUTPUT_(+))
unnamed: MK64.1 (OUTPUT_(+)), SW56.3 (OUTPUT_(+)), SW64.8 (OUTPUT_(+))
unnamed: R6.2, R7.1, SW8.6 (OUTPUT_(+))
unnamed: R7.2, R8.1, SW8.5 (GND_(-))
unnamed: R8.2, R9.1, SW16.6 (OUTPUT_(+))
unnamed: R9.2, R10.1, SW16.5 (GND_(-))
unnamed: R10.2, R11.1, SW24.6 (OUTPUT_(+))
unnamed: R11.2, R12.1, SW24.5 (GND_(-))
unnamed: R12.2, R13.1, SW32.6 (OUTPUT_(+))
unnamed: R13.2, R14.1, SW32.5 (GND_(-))
unnamed: R14.2, R15.1, SW40.6 (OUTPUT_(+))
unnamed: R15.2, R16.1, SW40.5 (GND_(-))
unnamed: R16.2, R17.1, SW48.6 (OUTPUT_(+))
unnamed: R17.2, R18.1, SW48.5 (GND_(-))
unnamed: R18.2, R19.1, SW56.6 (OUTPUT_(+))
unnamed: R19.2, R20.1, SW56.5 (GND_(-))
unnamed: R20.2, R21.1, SW64.6 (OUTPUT_(+))
unnamed: R21.2, R22.1, SW64.5 (GND_(-))
unnamed: R22.2, TP7.1 (1_1)
unnamed: SW1.4 (GND_(-)), SW9.7 (GND_(-))
unnamed: SW1.5 (GND_(-)), SW2.2 (GND_(-))
unnamed: SW1.6 (OUTPUT_(+)), SW2.1 (OUTPUT_(+))
unnamed: SW2.5 (GND_(-)), SW3.2 (GND_(-))
unnamed: SW2.6 (OUTPUT_(+)), SW3.1 (OUTPUT_(+))
unnamed: SW3.5 (GND_(-)), SW4.2 (GND_(-))
unnamed: SW3.6 (OUTPUT_(+)), SW4.1 (OUTPUT_(+))
unnamed: SW4.5 (GND_(-)), SW5.2 (GND_(-))
unnamed: SW4.6 (OUTPUT_(+)), SW5.1 (OUTPUT_(+))
unnamed: SW5.5 (GND_(-)), SW6.2 (GND_(-))
unnamed: SW5.6 (OUTPUT_(+)), SW6.1 (OUTPUT_(+))
unnamed: SW6.5 (GND_(-)), SW7.2 (GND_(-))
unnamed: SW6.6 (OUTPUT_(+)), SW7.1 (OUTPUT_(+))
unnamed: SW7.5 (GND_(-)), SW8.2 (GND_(-))
unnamed: SW7.6 (OUTPUT_(+)), SW8.1 (OUTPUT_(+))
unnamed: SW9.5 (GND_(-)), SW10.2 (GND_(-))
unnamed: SW10.4 (GND_(-)), SW18.7 (GND_(-))
unnamed: SW10.5 (GND_(-)), SW11.2 (GND_(-))
unnamed: SW2.4 (GND_(-)), SW10.7 (GND_(-))
unnamed: SW9.6 (OUTPUT_(+)), SW10.1 (OUTPUT_(+))
unnamed: SW10.6 (OUTPUT_(+)), SW11.1 (OUTPUT_(+))
unnamed: SW11.4 (GND_(-)), SW19.7 (GND_(-))
unnamed: SW11.5 (GND_(-)), SW12.2 (GND_(-))
unnamed: SW3.4 (GND_(-)), SW11.7 (GND_(-))
unnamed: SW11.6 (OUTPUT_(+)), SW12.1 (OUTPUT_(+))
unnamed: SW12.4 (GND_(-)), SW20.7 (GND_(-))
unnamed: SW12.5 (GND_(-)), SW13.2 (GND_(-))
unnamed: SW4.4 (GND_(-)), SW12.7 (GND_(-))
unnamed: SW12.6 (OUTPUT_(+)), SW13.1 (OUTPUT_(+))
unnamed: SW13.4 (GND_(-)), SW21.7 (GND_(-))
unnamed: SW13.5 (GND_(-)), SW14.2 (GND_(-))
unnamed: SW5.4 (GND_(-)), SW13.7 (GND_(-))
unnamed: SW13.6 (OUTPUT_(+)), SW14.1 (OUTPUT_(+))
unnamed: SW14.4 (GND_(-)), SW22.7 (GND_(-))
unnamed: SW14.5 (GND_(-)), SW15.2 (GND_(-))
unnamed: SW6.4 (GND_(-)), SW14.7 (GND_(-))
unnamed: SW14.6 (OUTPUT_(+)), SW15.1 (OUTPUT_(+))
unnamed: SW15.4 (GND_(-)), SW23.7 (GND_(-))
unnamed: SW15.5 (GND_(-)), SW16.2 (GND_(-))
unnamed: SW7.4 (GND_(-)), SW15.7 (GND_(-))
unnamed: SW15.6 (OUTPUT_(+)), SW16.1 (OUTPUT_(+))
unnamed: SW16.4 (GND_(-)), SW24.7 (GND_(-))
unnamed: SW8.4 (GND_(-)), SW16.7 (GND_(-))
unnamed: SW17.4 (GND_(-)), SW25.7 (GND_(-))
unnamed: SW17.5 (GND_(-)), SW18.2 (GND_(-))
unnamed: SW9.4 (GND_(-)), SW17.7 (GND_(-))
unnamed: SW17.6 (OUTPUT_(+)), SW18.1 (OUTPUT_(+))
unnamed: SW18.4 (GND_(-)), SW26.7 (GND_(-))
unnamed: SW18.5 (GND_(-)), SW19.2 (GND_(-))
unnamed: SW18.6 (OUTPUT_(+)), SW19.1 (OUTPUT_(+))
unnamed: SW19.4 (GND_(-)), SW27.7 (GND_(-))
unnamed: SW19.5 (GND_(-)), SW20.2 (GND_(-))
unnamed: SW19.6 (OUTPUT_(+)), SW20.1 (OUTPUT_(+))
unnamed: SW20.4 (GND_(-)), SW28.7 (GND_(-))
unnamed: SW20.5 (GND_(-)), SW21.2 (GND_(-))
unnamed: SW20.6 (OUTPUT_(+)), SW21.1 (OUTPUT_(+))
unnamed: SW21.4 (GND_(-)), SW29.7 (GND_(-))
unnamed: SW21.5 (GND_(-)), SW22.2 (GND_(-))
unnamed: SW21.6 (OUTPUT_(+)), SW22.1 (OUTPUT_(+))
unnamed: SW22.4 (GND_(-)), SW30.7 (GND_(-))
unnamed: SW22.5 (GND_(-)), SW23.2 (GND_(-))
unnamed: SW22.6 (OUTPUT_(+)), SW23.1 (OUTPUT_(+))
unnamed: SW23.4 (GND_(-)), SW31.7 (GND_(-))
unnamed: SW23.5 (GND_(-)), SW24.2 (GND_(-))
unnamed: SW23.6 (OUTPUT_(+)), SW24.1 (OUTPUT_(+))
unnamed: SW24.4 (GND_(-)), SW32.7 (GND_(-))
unnamed: SW25.4 (GND_(-)), SW33.7 (GND_(-))
unnamed: SW25.5 (GND_(-)), SW26.2 (GND_(-))
unnamed: SW25.6 (OUTPUT_(+)), SW26.1 (OUTPUT_(+))
unnamed: SW26.4 (GND_(-)), SW34.7 (GND_(-))
unnamed: SW26.5 (GND_(-)), SW27.2 (GND_(-))
unnamed: SW26.6 (OUTPUT_(+)), SW27.1 (OUTPUT_(+))
unnamed: SW27.4 (GND_(-)), SW35.7 (GND_(-))
unnamed: SW27.5 (GND_(-)), SW28.2 (GND_(-))
unnamed: SW27.6 (OUTPUT_(+)), SW28.1 (OUTPUT_(+))
unnamed: SW28.4 (GND_(-)), SW36.7 (GND_(-))
unnamed: SW28.5 (GND_(-)), SW29.2 (GND_(-))
unnamed: SW28.6 (OUTPUT_(+)), SW29.1 (OUTPUT_(+))
unnamed: SW29.4 (GND_(-)), SW37.7 (GND_(-))
unnamed: SW29.5 (GND_(-)), SW30.2 (GND_(-))
unnamed: SW29.6 (OUTPUT_(+)), SW30.1 (OUTPUT_(+))
unnamed: SW30.4 (GND_(-)), SW38.7 (GND_(-))
unnamed: SW30.5 (GND_(-)), SW31.2 (GND_(-))
unnamed: SW30.6 (OUTPUT_(+)), SW31.1 (OUTPUT_(+))
unnamed: SW31.4 (GND_(-)), SW39.7 (GND_(-))
unnamed: SW31.5 (GND_(-)), SW32.2 (GND_(-))
unnamed: SW31.6 (OUTPUT_(+)), SW32.1 (OUTPUT_(+))
unnamed: SW32.4 (GND_(-)), SW40.7 (GND_(-))
unnamed: SW33.4 (GND_(-)), SW41.7 (GND_(-))
unnamed: SW33.5 (GND_(-)), SW34.2 (GND_(-))
unnamed: SW33.6 (OUTPUT_(+)), SW34.1 (OUTPUT_(+))
unnamed: SW34.4 (GND_(-)), SW42.7 (GND_(-))
unnamed: SW34.5 (GND_(-)), SW35.2 (GND_(-))
unnamed: SW34.6 (OUTPUT_(+)), SW35.1 (OUTPUT_(+))
unnamed: SW35.4 (GND_(-)), SW43.7 (GND_(-))
unnamed: SW35.5 (GND_(-)), SW36.2 (GND_(-))
unnamed: SW35.6 (OUTPUT_(+)), SW36.1 (OUTPUT_(+))
unnamed: SW36.4 (GND_(-)), SW44.7 (GND_(-))
unnamed: SW36.5 (GND_(-)), SW37.2 (GND_(-))
unnamed: SW36.6 (OUTPUT_(+)), SW37.1 (OUTPUT_(+))
unnamed: SW37.4 (GND_(-)), SW45.7 (GND_(-))
unnamed: SW37.5 (GND_(-)), SW38.2 (GND_(-))
unnamed: SW37.6 (OUTPUT_(+)), SW38.1 (OUTPUT_(+))
unnamed: SW38.4 (GND_(-)), SW46.7 (GND_(-))
unnamed: SW38.5 (GND_(-)), SW39.2 (GND_(-))
unnamed: SW38.6 (OUTPUT_(+)), SW39.1 (OUTPUT_(+))
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

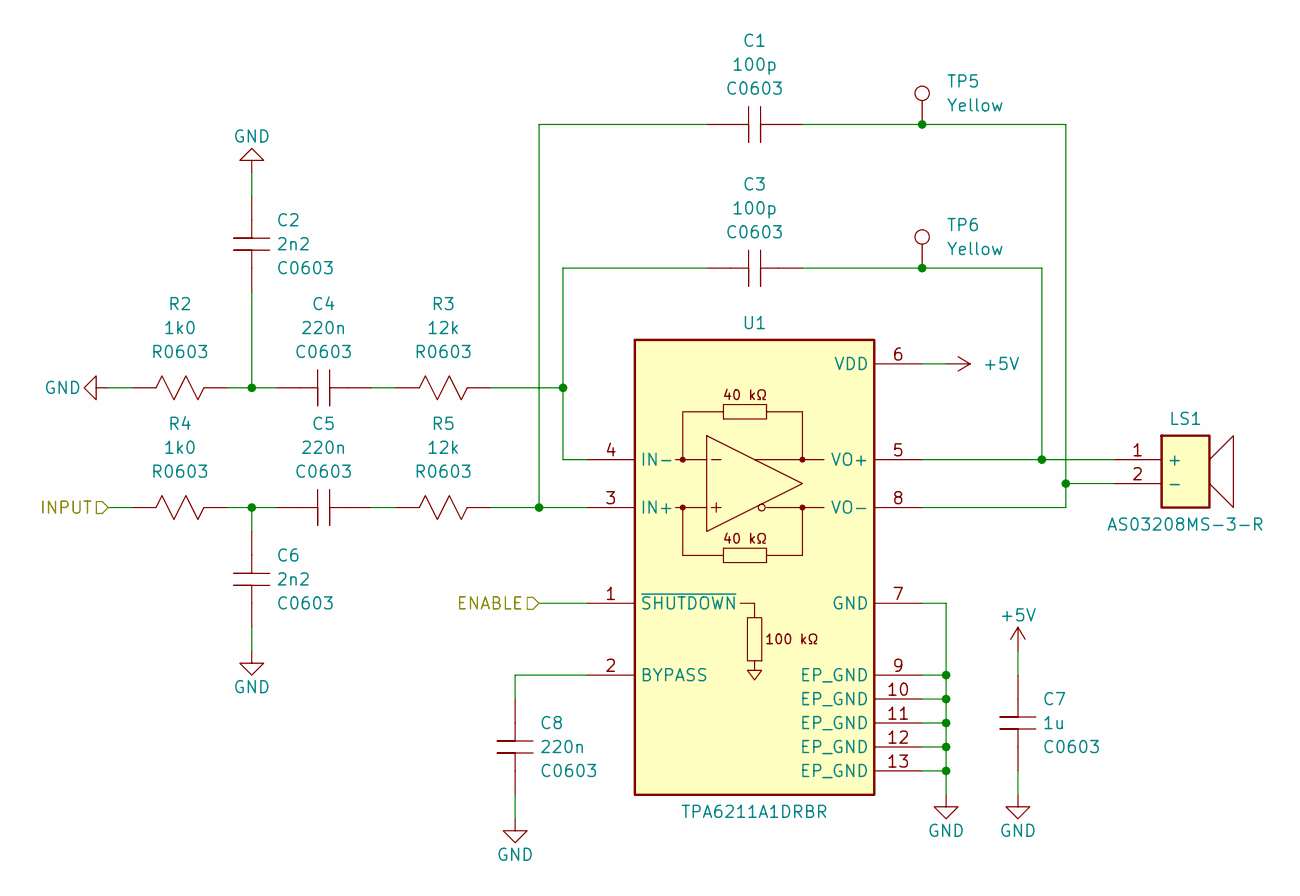
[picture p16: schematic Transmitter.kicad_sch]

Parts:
C1, C3: C0603_100p; C_0603_1608Metric; MPN KGM15AR71H101K
C2, C6: C0603_2n2; C_0603_1608Metric; MPN GRM1885C1H222JA01D
C4, C5, C8: C0603_220n; C_0603_1608Metric; MPN GCM188R71E224MA55J
C7: C0603_1u0; C_0603_1608Metric; MPN GRT188R61H105KE13D
LS1: AS03208MS-3-R; MPN AS03208MS-3-R
R2, R4: R0603_1k0; R_0603_1608Metric; MPN CRGP0603F1K0
R3, R5: R0603_12k; R_0603_1608Metric; MPN CRGP0603F12K
TP5, TP6: Keystone_5014_Yellow; TestPoint_Keystone_5010-5014_Multipurpose; MPN 5014
U1: TPA6211A1DRBR; TPS73719QDRBRQ1; MPN TPA6211A1DRBR

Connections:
+5V: C7.1, U1.6 (VDD); also elsewhere on the board
/Control_Power/PA_ENABLE: U1.1 (~SHUTDOWN); also elsewhere on the board
/Control_Power/PWM: R4.1; also elsewhere on the board
GND: C2.1, C6.2, C7.2, C8.2, R2.1, U1.7 (GND), U1.9 (EP_GND), U1.10 (EP_GND), U1.11 (EP_GND), U1.12 (EP_GND), U1.13 (EP_GND); also elsewhere on the board
unnamed: C2.2, C4.1, R2.2
unnamed: C4.2, R3.1
unnamed: C5.1, C6.1, R4.2
unnamed: C5.2, R5.1
unnamed: C3.2, LS1.1 (+), TP6.1 (1_1), U1.5 (VO+)
unnamed: C1.2, LS1.2 (-), TP5.1 (1_1), U1.8 (VO-)
unnamed: C8.1, U1.2 (BYPASS)
unnamed: C1.1, R5.2, U1.3 (IN+)
unnamed: C3.1, R3.2, U1.4 (IN-)

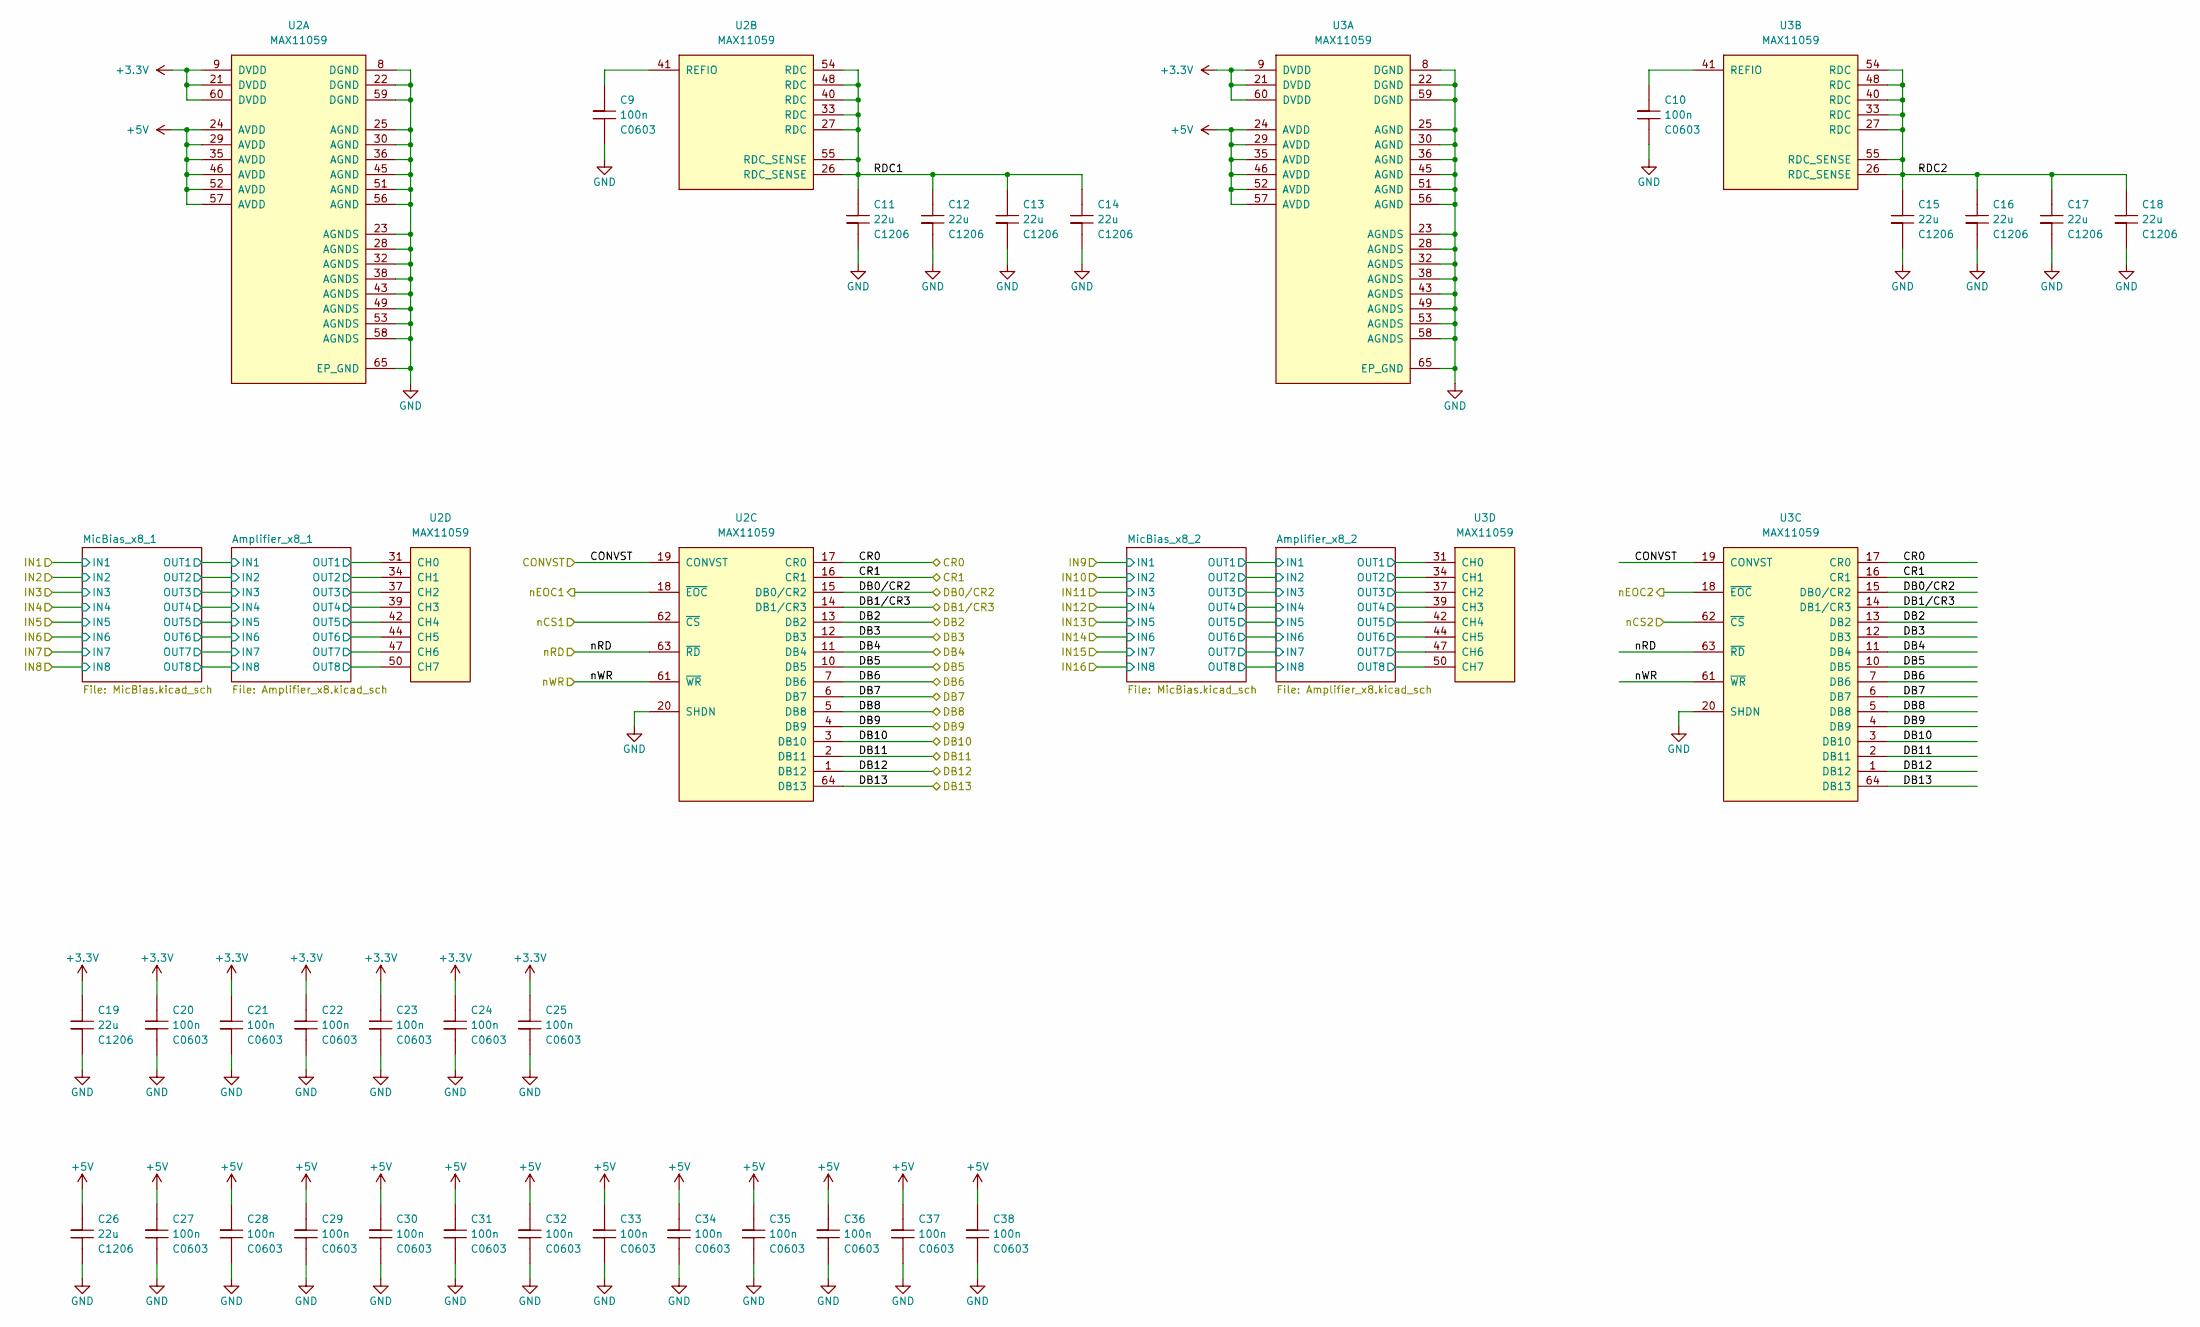
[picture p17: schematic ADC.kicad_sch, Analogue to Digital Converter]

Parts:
C9, C10, C20, C21, C22, C23, C24, C25, C27, C28, C29, C30, C31, C32, C33, C34, C35, C36, C37, C38: C0603_100n; C_0603_1608Metric; MPN 06035C104KAT2A
C11, C12, C13, C14, C15, C16, C17, C18, C19, C26: C1206_22u; C_1206_3216Metric; MPN C1206C226M4PACTU
U2, U3: MAX11059; Texas_TQFP-64-1EP_10x10mm_P0.5mm_EP8x8mm_Mask5x5mm; MPN MAX11059ECB+

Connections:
+3.3V: C19.1, C20.1, C21.1, C22.1, C23.1, C24.1, C25.1, U2.9 (DVDD), U2.21 (DVDD), U2.60 (DVDD), U3.9 (DVDD), U3.21 (DVDD), U3.60 (DVDD); also elsewhere on the board
+5V: C26.1, C27.1, C28.1, C29.1, C30.1, C31.1, C32.1, C33.1, C34.1, C35.1, C36.1, C37.1, C38.1, U2.24 (AVDD), U2.29 (AVDD), U2.35 (AVDD), U2.46 (AVDD), U2.52 (AVDD), U2.57 (AVDD), U3.24 (AVDD), U3.29 (AVDD), U3.35 (AVDD), U3.46 (AVDD), U3.52 (AVDD), U3.57 (AVDD); also elsewhere on the board
/ADC/Amplifier_x8_1/OUT1: U2.31 (CH0); also elsewhere on the board
/ADC/Amplifier_x8_1/OUT2: U2.34 (CH1); also elsewhere on the board
/ADC/Amplifier_x8_1/OUT3: U2.37 (CH2); also elsewhere on the board
/ADC/Amplifier_x8_1/OUT4: U2.39 (CH3); also elsewhere on the board
/ADC/Amplifier_x8_1/OUT5: U2.42 (CH4); also elsewhere on the board
/ADC/Amplifier_x8_1/OUT6: U2.44 (CH5); also elsewhere on the board
/ADC/Amplifier_x8_1/OUT7: U2.47 (CH6); also elsewhere on the board
/ADC/Amplifier_x8_1/OUT8: U2.50 (CH7); also elsewhere on the board
/ADC/Amplifier_x8_2/OUT1: U3.31 (CH0); also elsewhere on the board
/ADC/Amplifier_x8_2/OUT2: U3.34 (CH1); also elsewhere on the board
/ADC/Amplifier_x8_2/OUT3: U3.37 (CH2); also elsewhere on the board
/ADC/Amplifier_x8_2/OUT4: U3.39 (CH3); also elsewhere on the board
/ADC/Amplifier_x8_2/OUT5: U3.42 (CH4); also elsewhere on the board
/ADC/Amplifier_x8_2/OUT6: U3.44 (CH5); also elsewhere on the board
/ADC/Amplifier_x8_2/OUT7: U3.47 (CH6); also elsewhere on the board
/ADC/Amplifier_x8_2/OUT8: U3.50 (CH7); also elsewhere on the board
/ADC/CONVST: U2.19 (CONVST), U3.19 (CONVST); also elsewhere on the board
/ADC/CR0: U2.17 (CR0), U3.17 (CR0); also elsewhere on the board
/ADC/CR1: U2.16 (CR1), U3.16 (CR1); also elsewhere on the board
/ADC/DB0/CR2: U2.15 (DB0/CR2), U3.15 (DB0/CR2); also elsewhere on the board
/ADC/DB1/CR3: U2.14 (DB1/CR3), U3.14 (DB1/CR3); also elsewhere on the board
/ADC/DB2: U2.13 (DB2), U3.13 (DB2); also elsewhere on the board
/ADC/DB3: U2.12 (DB3), U3.12 (DB3); also elsewhere on the board
/ADC/DB4: U2.11 (DB4), U3.11 (DB4); also elsewhere on the board
/ADC/DB5: U2.10 (DB5), U3.10 (DB5); also elsewhere on the board
/ADC/DB6: U2.7 (DB6), U3.7 (DB6); also elsewhere on the board
/ADC/DB7: U2.6 (DB7), U3.6 (DB7); also elsewhere on the board
/ADC/DB8: U2.5 (DB8), U3.5 (DB8); also elsewhere on the board
/ADC/DB9: U2.4 (DB9), U3.4 (DB9); also elsewhere on the board
/ADC/DB10: U2.3 (DB10), U3.3 (DB10); also elsewhere on the board
/ADC/DB11: U2.2 (DB11), U3.2 (DB11); also elsewhere on the board
/ADC/DB12: U2.1 (DB12), U3.1 (DB12); also elsewhere on the board
/ADC/DB13: U2.64 (DB13), U3.64 (DB13); also elsewhere on the board
/ADC/RDC1: C11.1, C12.1, C13.1, C14.1, U2.26 (RDC_SENSE), U2.27 (RDC), U2.33 (RDC), U2.40 (RDC), U2.48 (RDC), U2.54 (RDC), U2.55 (RDC_SENSE)
/ADC/RDC2: C15.1, C16.1, C17.1, C18.1, U3.26 (RDC_SENSE), U3.27 (RDC), U3.33 (RDC), U3.40 (RDC), U3.48 (RDC), U3.54 (RDC), U3.55 (RDC_SENSE)
/ADC/nCS1: U2.62 (~CS); also elsewhere on the board
/ADC/nCS2: U3.62 (~CS); also elsewhere on the board
/ADC/nEOC1: U2.18 (~EOC); also elsewhere on the board
/ADC/nEOC2: U3.18 (~EOC); also elsewhere on the board
/ADC/nRD: U2.63 (~RD), U3.63 (~RD); also elsewhere on the board
/ADC/nWR: U2.61 (~WR), U3.61 (~WR); also elsewhere on the board
GND: C9.2, C10.2, C11.2, C12.2, C13.2, C14.2, C15.2, C16.2, C17.2, C18.2, C19.2, C20.2, C21.2, C22.2, C23.2, C24.2, C25.2, C26.2, C27.2, C28.2, C29.2, C30.2, C31.2, C32.2, C33.2, C34.2, C35.2, C36.2, C37.2, C38.2, U2.8 (DGND), U2.20 (SHDN), U2.22 (DGND), U2.23 (AGNDS), U2.25 (AGND), U2.28 (AGNDS), U2.30 (AGND), U2.32 (AGNDS), U2.36 (AGND), U2.38 (AGNDS), U2.43 (AGNDS), U2.45 (AGND), U2.49 (AGNDS), U2.51 (AGND), U2.53 (AGNDS), U2.56 (AGND), U2.58 (AGNDS), U2.59 (DGND), U2.65 (EP_GND), U3.8 (DGND), U3.20 (SHDN), U3.22 (DGND), U3.23 (AGNDS), U3.25 (AGND), U3.28 (AGNDS), U3.30 (AGND), U3.32 (AGNDS), U3.36 (AGND), U3.38 (AGNDS), U3.43 (AGNDS), U3.45 (AGND), U3.49 (AGNDS), U3.51 (AGND), U3.53 (AGNDS), U3.56 (AGND), U3.58 (AGNDS), U3.59 (DGND), U3.65 (EP_GND); also elsewhere on the board
unnamed: C9.1, U2.41 (REFIO)
unnamed: C10.1, U3.41 (REFIO)

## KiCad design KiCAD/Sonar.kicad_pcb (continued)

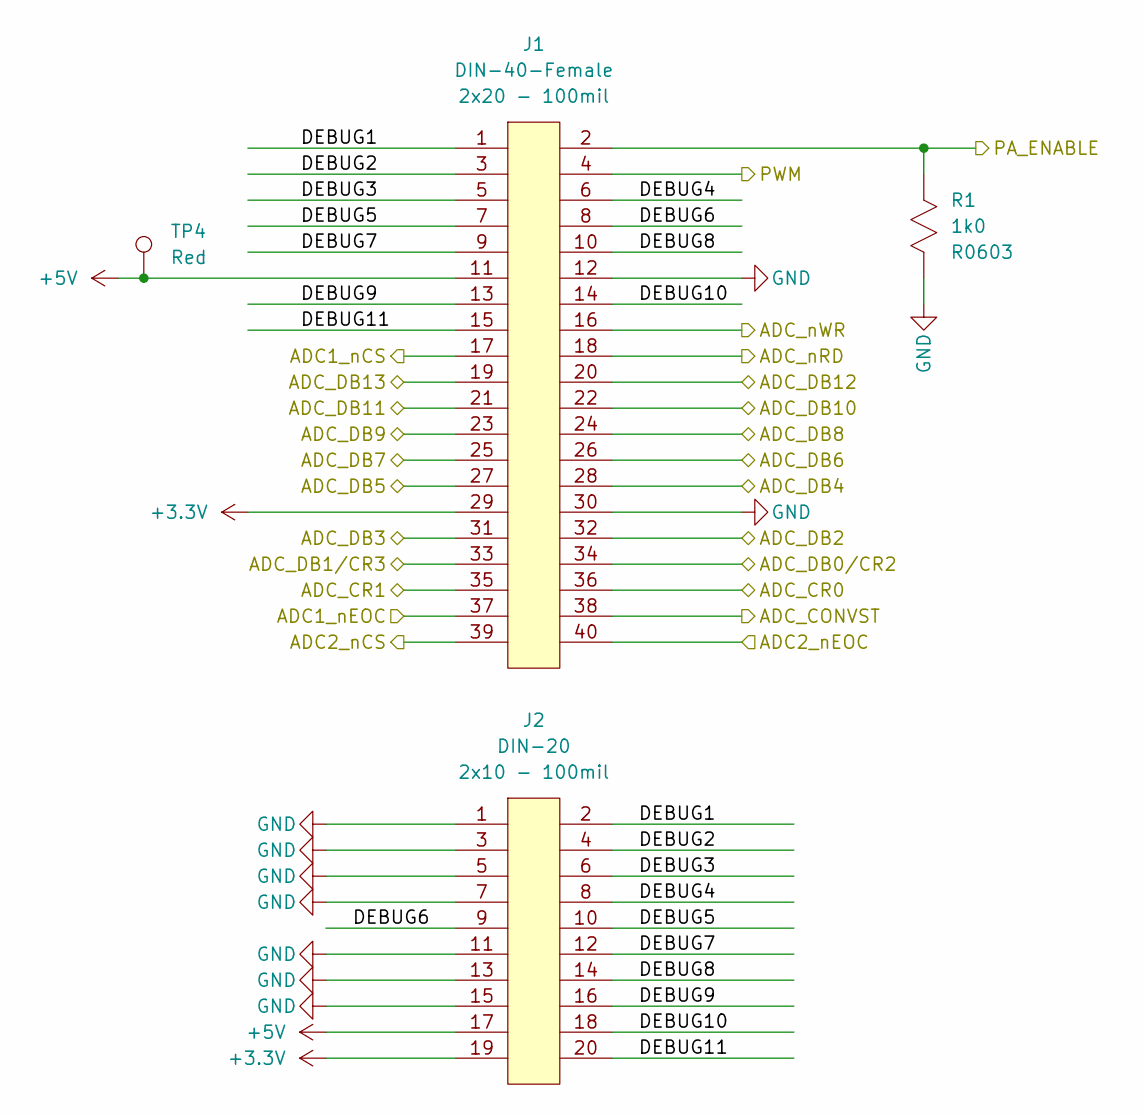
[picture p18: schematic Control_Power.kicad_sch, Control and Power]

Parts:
J1: DIN-40-Female; PinSocket_2x20_P2.54mm_Vertical; MPN M20-7832042
J2: DIN-20; IDC-Header_2x10_P2.54mm_Vertical; MPN 70246-2004
R1: R0603_1k0; R_0603_1608Metric; MPN CRGP0603F1K0
TP4: Keystone_5010_Red; TestPoint_Keystone_5010-5014_Multipurpose; MPN 5010

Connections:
+3.3V: J1.29, J2.19; also elsewhere on the board
+5V: J1.11, J2.17, TP4.1 (1_1); also elsewhere on the board
/ADC/CONVST: J1.38; also elsewhere on the board
/ADC/CR0: J1.36; also elsewhere on the board
/ADC/CR1: J1.35; also elsewhere on the board
/ADC/DB0/CR2: J1.34; also elsewhere on the board
/ADC/DB1/CR3: J1.33; also elsewhere on the board
/ADC/DB2: J1.32; also elsewhere on the board
/ADC/DB3: J1.31; also elsewhere on the board
/ADC/DB4: J1.28; also elsewhere on the board
/ADC/DB5: J1.27; also elsewhere on the board
/ADC/DB6: J1.26; also elsewhere on the board
/ADC/DB7: J1.25; also elsewhere on the board
/ADC/DB8: J1.24; also elsewhere on the board
/ADC/DB9: J1.23; also elsewhere on the board
/ADC/DB10: J1.22; also elsewhere on the board
/ADC/DB11: J1.21; also elsewhere on the board
/ADC/DB12: J1.20; also elsewhere on the board
/ADC/DB13: J1.19; also elsewhere on the board
/ADC/nCS1: J1.17; also elsewhere on the board
/ADC/nCS2: J1.39; also elsewhere on the board
/ADC/nEOC1: J1.37; also elsewhere on the board
/ADC/nEOC2: J1.40; also elsewhere on the board
/ADC/nRD: J1.18; also elsewhere on the board
/ADC/nWR: J1.16; also elsewhere on the board
/Control_Power/DEBUG1: J1.1, J2.2
/Control_Power/DEBUG2: J1.3, J2.4
/Control_Power/DEBUG3: J1.5, J2.6
/Control_Power/DEBUG4: J1.6, J2.8
/Control_Power/DEBUG5: J1.7, J2.10
/Control_Power/DEBUG6: J1.8, J2.9
/Control_Power/DEBUG7: J1.9, J2.12
/Control_Power/DEBUG8: J1.10, J2.14
/Control_Power/DEBUG9: J1.13, J2.16
/Control_Power/DEBUG10: J1.14, J2.18
/Control_Power/DEBUG11: J1.15, J2.20
/Control_Power/PA_ENABLE: J1.2, R1.1; also elsewhere on the board
/Control_Power/PWM: J1.4; also elsewhere on the board
GND: J1.12, J1.30, J2.1, J2.3, J2.5, J2.7, J2.11, J2.13, J2.15, R1.2; also elsewhere on the board

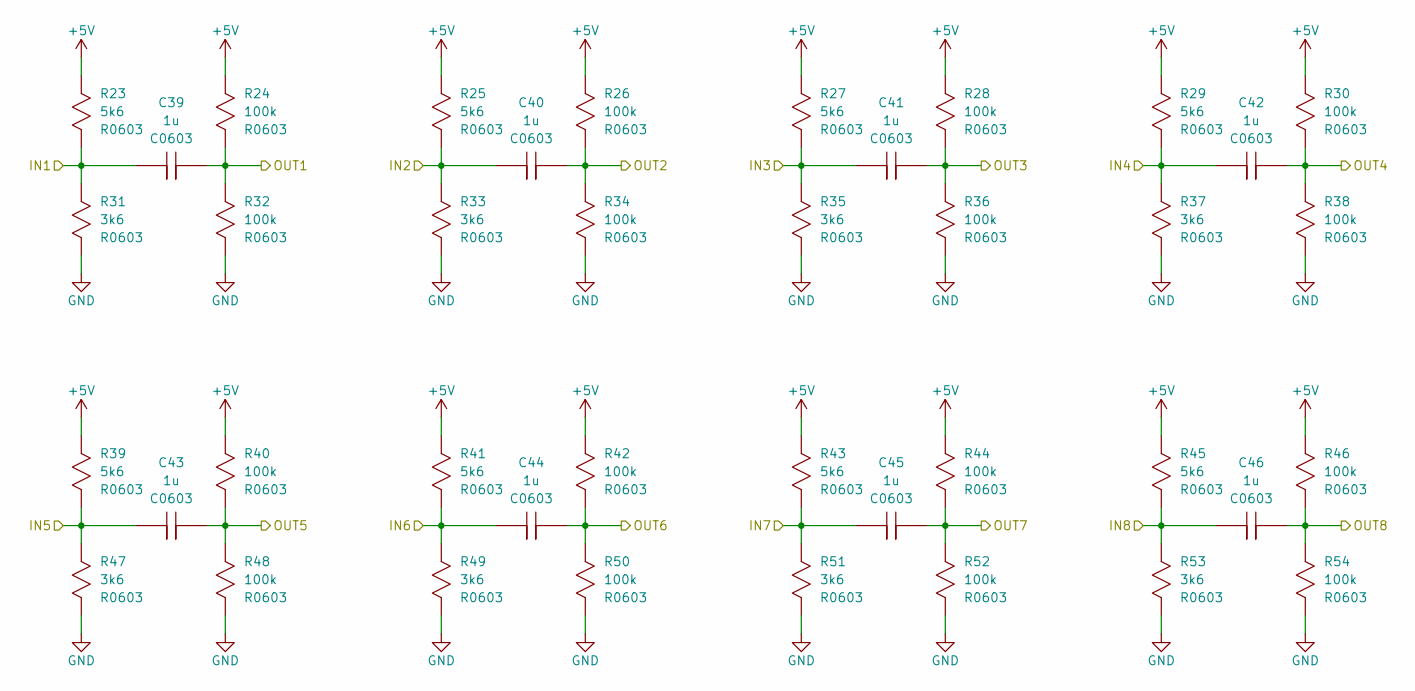
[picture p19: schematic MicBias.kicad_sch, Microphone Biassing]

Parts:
C39, C40, C41, C42, C43, C44, C45, C46: C0603_1u0; C_0603_1608Metric; MPN GRT188R61H105KE13D
R23, R25, R27, R29, R39, R41, R43, R45: R0603_5k6; R_0603_1608Metric; MPN CRGP0603F5K6
R24, R26, R28, R30, R32, R34, R36, R38, R40, R42, R44, R46, R48, R50, R52, R54: R0603_100k; R_0603_1608Metric; MPN CRGP0603F100K
R31, R33, R35, R37, R47, R49, R51, R53: R0603_3k6; R_0603_1608Metric; MPN CRGP0603F3K6

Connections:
+5V: R23.1, R24.1, R25.1, R26.1, R27.1, R28.1, R29.1, R30.1, R39.1, R40.1, R41.1, R42.1, R43.1, R44.1, R45.1, R46.1; also elsewhere on the board
/ADC/Amplifier_x8_1/IN1: C39.2, R24.2, R32.1; also elsewhere on the board
/ADC/Amplifier_x8_1/IN2: C40.2, R26.2, R34.1; also elsewhere on the board
/ADC/Amplifier_x8_1/IN3: C41.2, R28.2, R36.1; also elsewhere on the board
/ADC/Amplifier_x8_1/IN4: C42.2, R30.2, R38.1; also elsewhere on the board
/ADC/Amplifier_x8_1/IN5: C43.2, R40.2, R48.1; also elsewhere on the board
/ADC/Amplifier_x8_1/IN6: C44.2, R42.2, R50.1; also elsewhere on the board
/ADC/Amplifier_x8_1/IN7: C45.2, R44.2, R52.1; also elsewhere on the board
/ADC/Amplifier_x8_1/IN8: C46.2, R46.2, R54.1; also elsewhere on the board
/ADC/IN1: C39.1, R23.2, R31.1; also elsewhere on the board
/ADC/IN2: C40.1, R25.2, R33.1; also elsewhere on the board
/ADC/IN3: C41.1, R27.2, R35.1; also elsewhere on the board
/ADC/IN4: C42.1, R29.2, R37.1; also elsewhere on the board
/ADC/IN5: C43.1, R39.2, R47.1; also elsewhere on the board
/ADC/IN6: C44.1, R41.2, R49.1; also elsewhere on the board
/ADC/IN7: C45.1, R43.2, R51.1; also elsewhere on the board
/ADC/IN8: C46.1, R45.2, R53.1; also elsewhere on the board
GND: R31.2, R32.2, R33.2, R34.2, R35.2, R36.2, R37.2, R38.2, R47.2, R48.2, R49.2, R50.2, R51.2, R52.2, R53.2, R54.2; also elsewhere on the board

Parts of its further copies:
C47, C48, C49, C50, C51, C52, C53, C54: C0603_1u0; C_0603_1608Metric; MPN GRT188R61H105KE13D
R55, R57, R59, R61, R71, R73, R75, R77: R0603_5k6; R_0603_1608Metric; MPN CRGP0603F5K6
R56, R58, R60, R62, R64, R66, R68, R70, R72, R74, R76, R78, R80, R82, R84, R86: R0603_100k; R_0603_1608Metric; MPN CRGP0603F100K
R63, R65, R67, R69, R79, R81, R83, R85: R0603_3k6; R_0603_1608Metric; MPN CRGP0603F3K6

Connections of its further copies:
+5V: R55.1, R56.1, R57.1, R58.1, R59.1, R60.1, R61.1, R62.1, R71.1, R72.1, R73.1, R74.1, R75.1, R76.1, R77.1, R78.1; also elsewhere on the board
/ADC/Amplifier_x8_2/IN1: C47.2, R56.2, R64.1; also elsewhere on the board
/ADC/Amplifier_x8_2/IN2: C48.2, R58.2, R66.1; also elsewhere on the board
/ADC/Amplifier_x8_2/IN3: C49.2, R60.2, R68.1; also elsewhere on the board
/ADC/Amplifier_x8_2/IN4: C50.2, R62.2, R70.1; also elsewhere on the board
/ADC/Amplifier_x8_2/IN5: C51.2, R72.2, R80.1; also elsewhere on the board
/ADC/Amplifier_x8_2/IN6: C52.2, R74.2, R82.1; also elsewhere on the board
/ADC/Amplifier_x8_2/IN7: C53.2, R76.2, R84.1; also elsewhere on the board
/ADC/Amplifier_x8_2/IN8: C54.2, R78.2, R86.1; also elsewhere on the board
/ADC/IN9: C47.1, R55.2, R63.1; also elsewhere on the board
/ADC/IN10: C48.1, R57.2, R65.1; also elsewhere on the board
/ADC/IN11: C49.1, R59.2, R67.1; also elsewhere on the board
/ADC/IN12: C50.1, R61.2, R69.1; also elsewhere on the board
/ADC/IN13: C51.1, R71.2, R79.1; also elsewhere on the board
/ADC/IN14: C52.1, R73.2, R81.1; also elsewhere on the board
/ADC/IN15: C53.1, R75.2, R83.1; also elsewhere on the board
/ADC/IN16: C54.1, R77.2, R85.1; also elsewhere on the board
GND: R63.2, R64.2, R65.2, R66.2, R67.2, R68.2, R69.2, R70.2, R79.2, R80.2, R81.2, R82.2, R83.2, R84.2, R85.2, R86.2; also elsewhere on the board

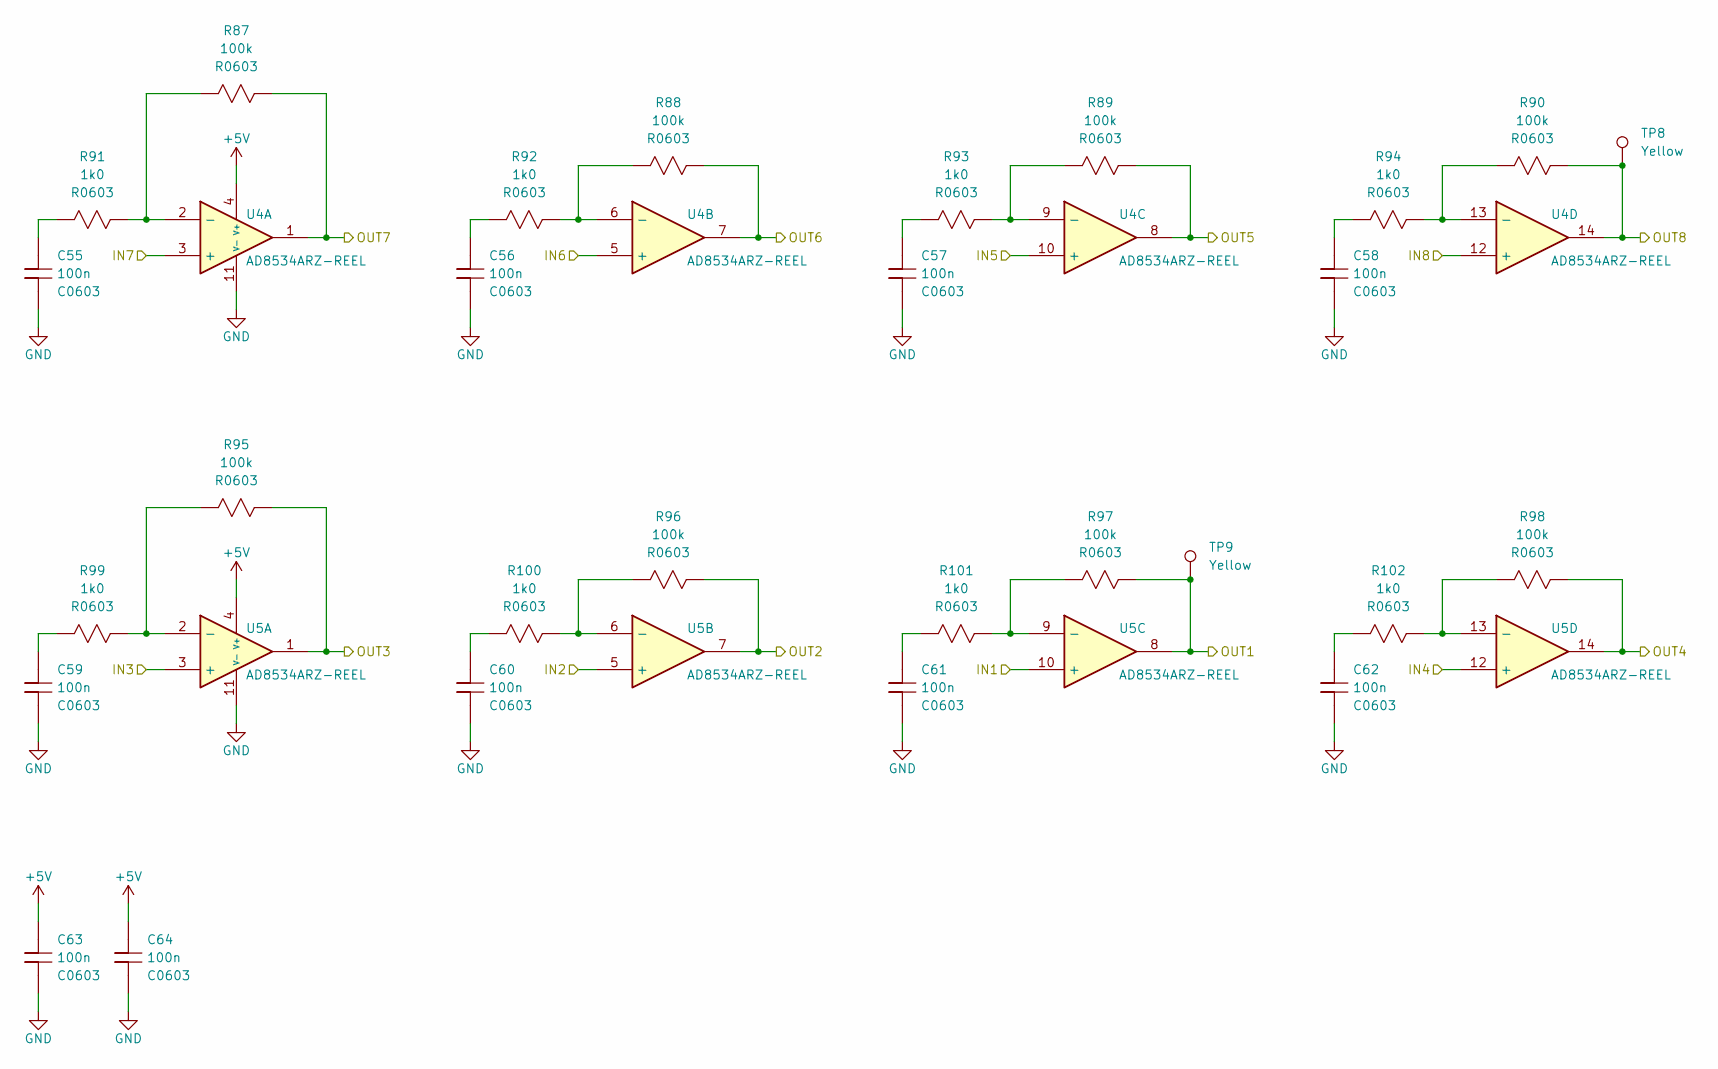
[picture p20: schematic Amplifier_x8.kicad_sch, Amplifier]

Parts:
C55, C56, C57, C58, C59, C60, C61, C62, C63, C64: C0603_100n; C_0603_1608Metric; MPN 06035C104KAT2A
R87, R88, R89, R90, R95, R96, R97, R98: R0603_100k; R_0603_1608Metric; MPN CRGP0603F100K
R91, R92, R93, R94, R99, R100, R101, R102: R0603_1k0; R_0603_1608Metric; MPN CRGP0603F1K0
TP8, TP9: Keystone_5014_Yellow; TestPoint_Keystone_5010-5014_Multipurpose; MPN 5014
U4, U5: AD8534ARZ-REEL; SOIC127P600X175-14N; MPN AD8534ARZ-REEL

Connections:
+5V: C63.1, C64.1, U4.4 (V+), U5.4 (V+); also elsewhere on the board
/ADC/Amplifier_x8_1/IN1: U5.10 (+); also elsewhere on the board
/ADC/Amplifier_x8_1/IN2: U5.5 (+); also elsewhere on the board
/ADC/Amplifier_x8_1/IN3: U5.3 (+); also elsewhere on the board
/ADC/Amplifier_x8_1/IN4: U5.12 (+); also elsewhere on the board
/ADC/Amplifier_x8_1/IN5: U4.10 (+); also elsewhere on the board
/ADC/Amplifier_x8_1/IN6: U4.5 (+); also elsewhere on the board
/ADC/Amplifier_x8_1/IN7: U4.3 (+); also elsewhere on the board
/ADC/Amplifier_x8_1/IN8: U4.12 (+); also elsewhere on the board
/ADC/Amplifier_x8_1/OUT1: R97.2, TP9.1 (1_1), U5.8; also elsewhere on the board
/ADC/Amplifier_x8_1/OUT2: R96.2, U5.7; also elsewhere on the board
/ADC/Amplifier_x8_1/OUT3: R95.2, U5.1; also elsewhere on the board
/ADC/Amplifier_x8_1/OUT4: R98.2, U5.14; also elsewhere on the board
/ADC/Amplifier_x8_1/OUT5: R89.2, U4.8; also elsewhere on the board
/ADC/Amplifier_x8_1/OUT6: R88.2, U4.7; also elsewhere on the board
/ADC/Amplifier_x8_1/OUT7: R87.2, U4.1; also elsewhere on the board
/ADC/Amplifier_x8_1/OUT8: R90.2, TP8.1 (1_1), U4.14; also elsewhere on the board
GND: C55.2, C56.2, C57.2, C58.2, C59.2, C60.2, C61.2, C62.2, C63.2, C64.2, U4.11 (V-), U5.11 (V-); also elsewhere on the board
unnamed: C55.1, R91.1
unnamed: C56.1, R92.1
unnamed: C57.1, R93.1
unnamed: C58.1, R94.1
unnamed: C59.1, R99.1
unnamed: C60.1, R100.1
unnamed: C61.1, R101.1
unnamed: C62.1, R102.1
unnamed: R87.1, R91.2, U4.2 (-)
unnamed: R88.1, R92.2, U4.6 (-)
unnamed: R89.1, R93.2, U4.9 (-)
unnamed: R90.1, R94.2, U4.13 (-)
unnamed: R95.1, R99.2, U5.2 (-)
unnamed: R96.1, R100.2, U5.6 (-)
unnamed: R97.1, R101.2, U5.9 (-)
unnamed: R98.1, R102.2, U5.13 (-)

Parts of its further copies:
C65, C66, C67, C68, C69, C70, C71, C72, C73, C74: C0603_100n; C_0603_1608Metric; MPN 06035C104KAT2A
R103, R104, R105, R106, R111, R112, R113, R114: R0603_100k; R_0603_1608Metric; MPN CRGP0603F100K
R107, R108, R109, R110, R115, R116, R117, R118: R0603_1k0; R_0603_1608Metric; MPN CRGP0603F1K0
TP10, TP11: Keystone_5014_Yellow; TestPoint_Keystone_5010-5014_Multipurpose; MPN 5014
U6, U7: AD8534ARZ-REEL; SOIC127P600X175-14N; MPN AD8534ARZ-REEL

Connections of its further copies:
+5V: C73.1, C74.1, U6.4 (V+), U7.4 (V+); also elsewhere on the board
/ADC/Amplifier_x8_2/IN1: U7.10 (+); also elsewhere on the board
/ADC/Amplifier_x8_2/IN2: U7.5 (+); also elsewhere on the board
/ADC/Amplifier_x8_2/IN3: U7.3 (+); also elsewhere on the board
/ADC/Amplifier_x8_2/IN4: U7.12 (+); also elsewhere on the board
/ADC/Amplifier_x8_2/IN5: U6.10 (+); also elsewhere on the board
/ADC/Amplifier_x8_2/IN6: U6.5 (+); also elsewhere on the board
/ADC/Amplifier_x8_2/IN7: U6.3 (+); also elsewhere on the board
/ADC/Amplifier_x8_2/IN8: U6.12 (+); also elsewhere on the board
/ADC/Amplifier_x8_2/OUT1: R113.2, TP11.1 (1_1), U7.8; also elsewhere on the board
/ADC/Amplifier_x8_2/OUT2: R112.2, U7.7; also elsewhere on the board
/ADC/Amplifier_x8_2/OUT3: R111.2, U7.1; also elsewhere on the board
/ADC/Amplifier_x8_2/OUT4: R114.2, U7.14; also elsewhere on the board
/ADC/Amplifier_x8_2/OUT5: R105.2, U6.8; also elsewhere on the board
/ADC/Amplifier_x8_2/OUT6: R104.2, U6.7; also elsewhere on the board
/ADC/Amplifier_x8_2/OUT7: R103.2, U6.1; also elsewhere on the board
/ADC/Amplifier_x8_2/OUT8: R106.2, TP10.1 (1_1), U6.14; also elsewhere on the board
GND: C65.2, C66.2, C67.2, C68.2, C69.2, C70.2, C71.2, C72.2, C73.2, C74.2, U6.11 (V-), U7.11 (V-); also elsewhere on the board
unnamed: C65.1, R107.1
unnamed: C66.1, R108.1
unnamed: C67.1, R109.1
unnamed: C68.1, R110.1
unnamed: C69.1, R115.1
unnamed: C70.1, R116.1
unnamed: C71.1, R117.1
unnamed: C72.1, R118.1
unnamed: R103.1, R107.2, U6.2 (-)
unnamed: R104.1, R108.2, U6.6 (-)
unnamed: R105.1, R109.2, U6.9 (-)
unnamed: R106.1, R110.2, U6.13 (-)
unnamed: R111.1, R115.2, U7.2 (-)
unnamed: R112.1, R116.2, U7.6 (-)
unnamed: R113.1, R117.2, U7.9 (-)
unnamed: R114.1, R118.2, U7.13 (-)

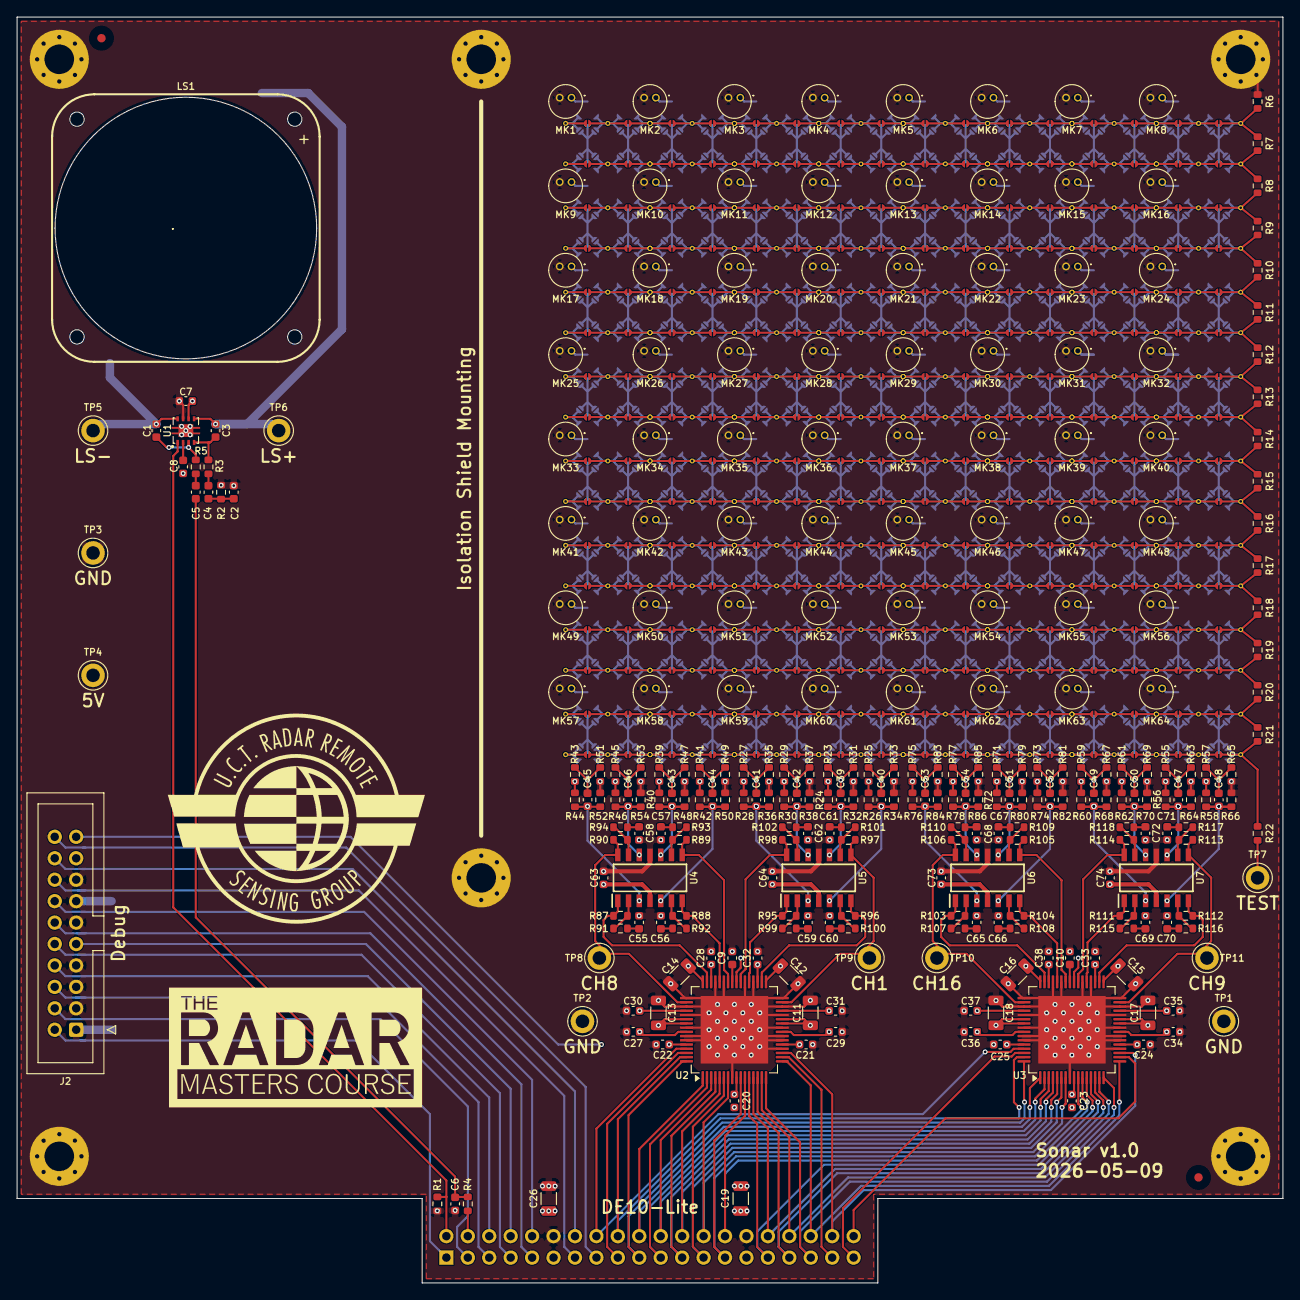
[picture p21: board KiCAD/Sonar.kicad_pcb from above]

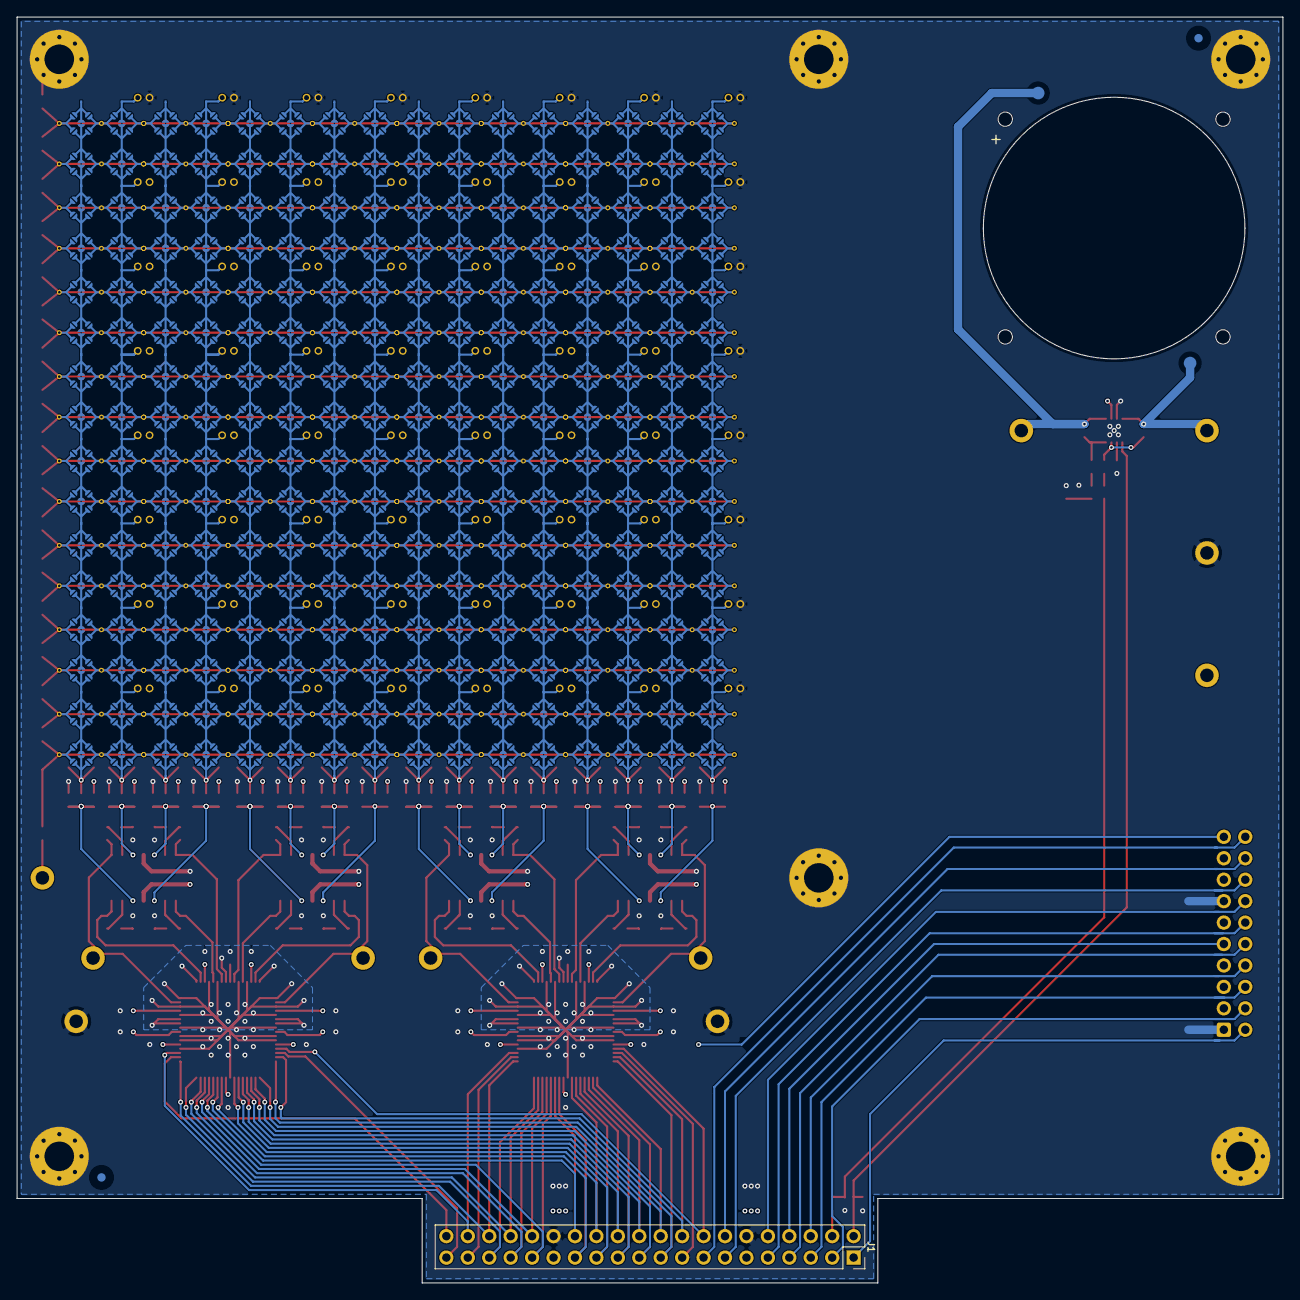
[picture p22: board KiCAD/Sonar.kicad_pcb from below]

Board: 4 copper layers, 150.0 x 150.0 mm, 353 parts (3 on the bottom side), 381 nets.

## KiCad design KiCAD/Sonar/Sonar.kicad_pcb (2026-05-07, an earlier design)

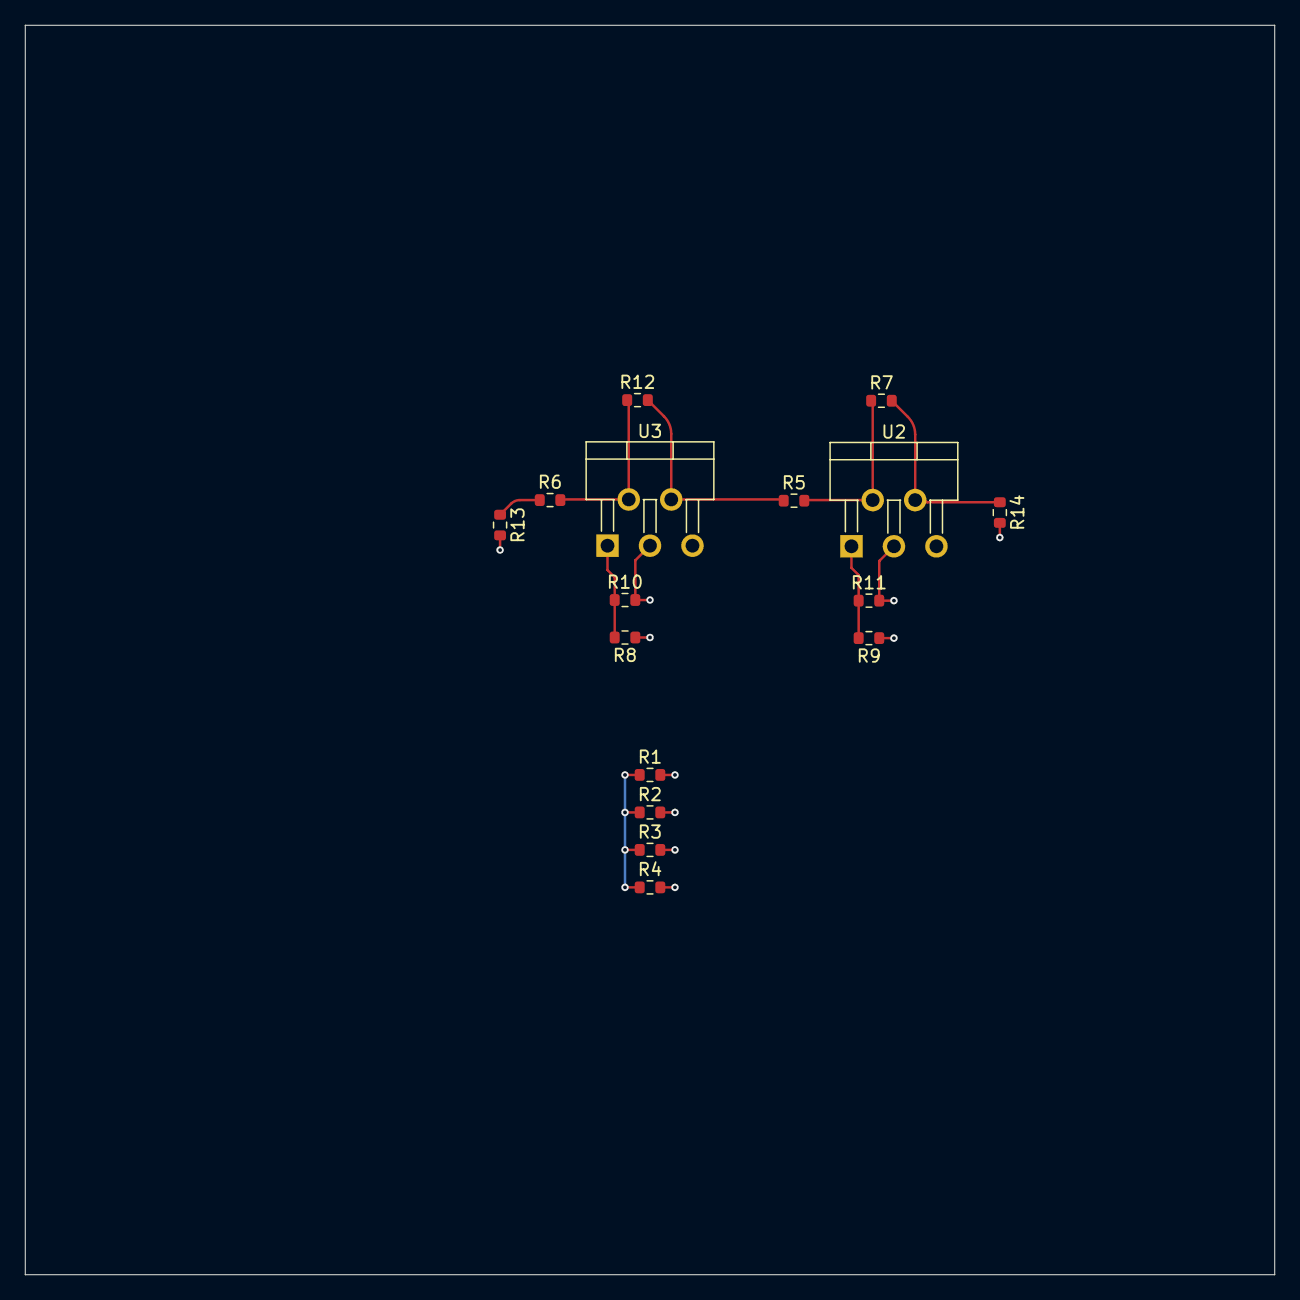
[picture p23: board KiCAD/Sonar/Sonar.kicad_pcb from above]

Board: 4 copper layers, 100.0 x 100.0 mm, 16 parts (0 on the bottom side), 10 nets.

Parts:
R1, R2, R3, R4, R5, R6, R7, R8, R9, R10, R11, R12, R13, R14: 1k; R_0603_1608Metric
U2, U3: LM1875; TO-220-5_P3.4x3.7mm_StaggerOdd_Lead3.8mm_Vertical

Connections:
+5V: R8.1, R9.1, U2.5 (V+), U3.5 (V+)
/Power/Input: R5.1, R12.2, U3.4
/Power/Output: R7.2, R14.1, U2.4
/Transducers/Input: R6.1, R13.1
GND: R1.2, R2.2, R3.2, R4.2, R10.2, R11.2, R13.2, R14.2, U2.3 (V-), U3.3 (V-)
unnamed: R1.1, R2.1, R3.1, R4.1
unnamed: R9.2, R11.1, U2.1 (+)
unnamed: R5.2, R7.1, U2.2 (-)
unnamed: R8.2, R10.1, U3.1 (+)
unnamed: R6.2, R12.1, U3.2 (-)

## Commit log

2026-05-07 Toy KiCAD project to get a feel for the tool
    [Inner.kicad_sch, Power.kicad_sch, Sonar.kicad_pcb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]
2026-05-07 Added some parts details
    [Inner.kicad_sch, Sonar.kicad_sch]
2026-05-07 Completed the schematic
    [ADC.kicad_sch, Amplifier_x8.kicad_sch, Control_Power.kicad_sch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]
2026-05-08 Drew the footprint for the cross-bar switch
2026-05-08 Finished routing
    [ADC.kicad_sch, Amplifier_x8.kicad_sch, Control_Power.kicad_sch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]
2026-05-08 Added RRSG and RadarMasters logos
    [Sonar.kicad_sch]
2026-05-08 Added a debug header
    [ADC.kicad_sch, Amplifier_x8.kicad_sch, Control_Power.kicad_sch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]
2026-05-08 Cosmetics and fiducials
    [Sonar.kicad_sch]
2026-05-08 Added test-points
    [Amplifier_x8.kicad_sch, Sonar.kicad_sch, Transmitter.kicad_sch]
2026-05-08 Organisd the assembly layer
2026-05-08 Set up and exported the BOM
    [ADC.kicad_sch, Amplifier_x8.kicad_sch, BOM.csv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]
2026-05-08 Set up and exported the CAM files
    [Sonar-B_Fab.gbr, Sonar-B_Mask.gbr, Sonar-B_Paste.gbr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]
2026-05-09 Added PA_Enable pull-down and moved the debug header
    [ADC.kicad_sch, Amplifier_x8.kicad_sch, Control_Power.kicad_sch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]
2026-05-09 Moved the microphone RL to per-channel instead of per-mic
    [ADC.kicad_sch, Amplifier_x8.kicad_sch, Control_Power.kicad_sch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]
2026-05-09 Added title block and version text
    [ADC.kicad_sch, Amplifier_x8.kicad_sch, Control_Power.kicad_sch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]
2026-05-09 Regenerated CAM output
    [ADC.kicad_sch, Amplifier_x8.kicad_sch, BOM.csv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]
2026-05-09 Final Updates:
    - Mounting holes for an isolation shield
    - 5V test-point to inject power
    - Test signal input with resistor ladder
    [ADC.kicad_sch, Amplifier_x8.kicad_sch, BOM.csv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]
2026-05-10 Updated speaker and microphone library path to "Transducers"
    [MicArray.kicad_sch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]
2026-05-10 Updated KiCAD/.gitignore to exclude zip files
2026-05-11 BOM EQ
    [EQ UCT Sonar PCB Manufacture_BOM .xlsx]
2026-05-11 Accepted the BOM updates
    [EQ UCT Sonar PCB Manufacture_BOM .xlsx]
2026-06-06 Changed 100pF and 100nF to AVX parts, and gave TPA6211 a pin-1 dot
    [ADC.kicad_sch, Amplifier_x8.kicad_sch, BOM.csv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]
2026-06-06 Regenerated the datapack
    [Sonar-B_Cu.gbr, Sonar-B_Fab.gbr, Sonar-B_Mask.gbr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]
2026-07-27 Removed the EQs folder
    [EQ UCT Sonar PCB Manufacture_BOM .xlsx]
